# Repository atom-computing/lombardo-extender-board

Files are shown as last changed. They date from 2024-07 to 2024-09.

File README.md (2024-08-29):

# Lombardo Extender Board

Extender board for the front-panel connector on the [DAMC-FMC2ZUP
carrier](https://innovation.desy.de/technologies/microtca/boards/damc_fmc2zup/index_eng.html)
(commercially available at [CAEN
ELS](https://www.caenels.com/product/damc-fmc2zup/)).

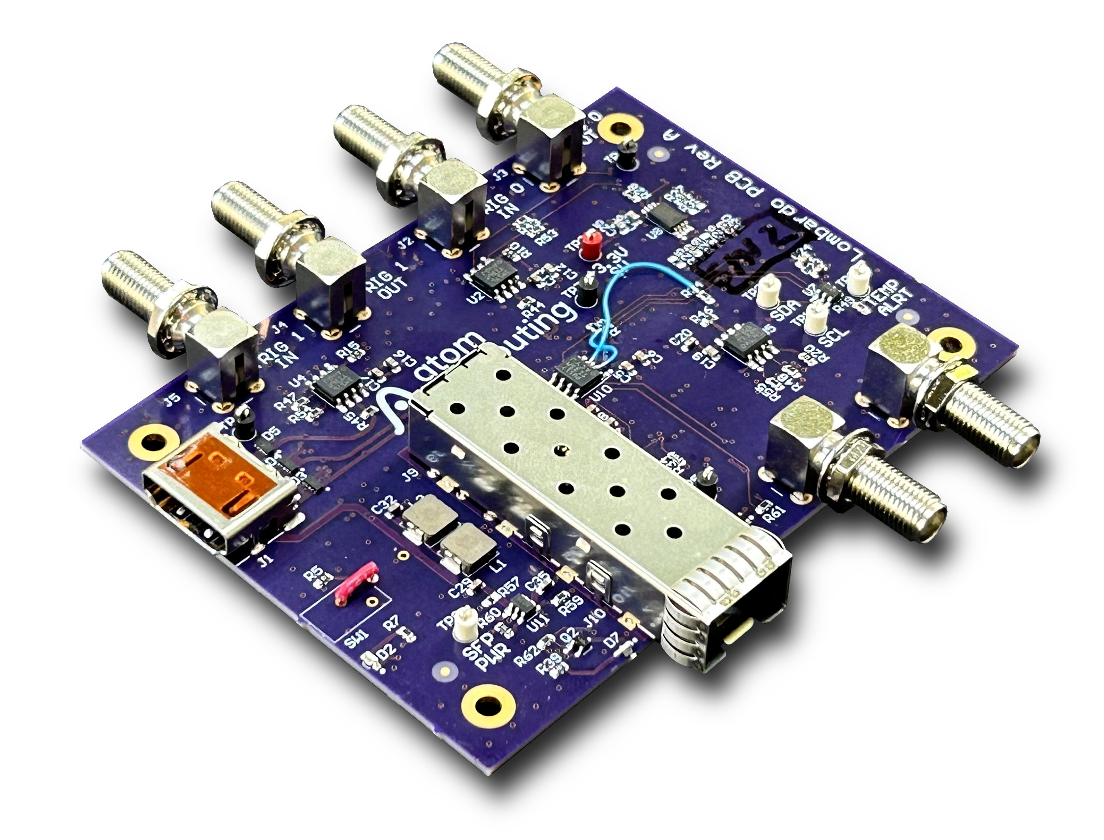
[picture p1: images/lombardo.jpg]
Lombardo Extender Board


## Features

* SFP+ cage, connected to the transceiver pins
* 2 trigger inputs and outputs (direction is SW configurable)
* clock input and output (direction is SW configurable)
* I2C EEPROM to store the identification information of the board
* I2C temperature sensor to monitor the board temperature

## License

Copyright (c) 2024, Atom Computing, Inc.

This project is licensed under CC BY-SA 4.0. See the [LICENSE.md](LICENSE.md)
file for details.

## Usage

### I2C communication, trigger and clock inputs/outputs

There are some I2C devices that need to be configured on this board at the
startup. The FPGA project on DAMC-FMC2ZUP should include an I2C controller
connected to the I2C bus that is connected to the front-panel connector. Please
refer to the [DAMC-FMC2ZUP - User's
Manual](https://www.caenels.com/product/damc-fmc2zup/) for information about the
pinout.

Similarly, all the differential pairs that are needed for triggers and clock
need to be instantiated.

### Connecting the board

Connect the board using to the front-panel connector of the DAMC-FMC2ZUP carrier
with a Micro HDMI to HDMI cable (see the list of tested cables
[below](#list-of-tested-hardware)) and turn on the switch. Please note that
some variants might not have a switch and the board turns on immediately when
connected to the carrier.

The LED D2 should turn on, indicating that the board is powered on.

### Initial check

Assuming you are running Linux on DAMC-FMC2ZUP, you can check whether the board
is operational by running `i2cdetect` command with the appropriate I2C bus
number (use `i2cdetect -l` to list all I2C buses).

```console
root@damc-fmc2zup:~# i2cdetect -l
i2c-3	i2c       	xiic-i2c [i2c_fplink]           	I2C adapter
i2c-1	i2c       	Cadence I2C at ff030000         	I2C adapter
i2c-4	i2c       	xiic-i2c [i2c_mmc]              	I2C adapter
i2c-2	i2c       	ZynqMP DP AUX                   	I2C adapter
i2c-0	i2c       	Cadence I2C at ff020000         	I2C adapter
i2c-5	i2c       	xiic-i2c [i2c_osc]              	I2C adapter
root@damc-fmc2zup:~# i2cdetect -r -y 3
     0  1  2  3  4  5  6  7  8  9  a  b  c  d  e  f
00:          -- -- -- -- -- -- -- -- -- -- -- -- --
10: -- -- -- -- -- -- -- -- -- -- -- -- -- -- -- --
20: -- -- -- -- -- -- -- -- -- -- -- -- -- -- -- --
30: -- -- -- -- -- -- -- -- -- 39 3a -- -- -- -- --
40: -- -- -- -- -- -- -- -- -- 49 -- -- -- -- -- --
50: -- -- -- -- 54 -- -- -- -- -- -- -- -- -- -- --
60: -- -- -- -- -- -- -- -- -- -- -- -- -- -- -- --
70: -- -- -- -- -- -- -- --
```

As shown in the example above, there should be 4 devices detected on the I2C
bus: 2 GPIO controllers at addresses 0x39 and 0x3a, an EEPROM at the address
0x54, and the temperature sensor at the address 0x49. When the SFP/SFP+ module
is enabled and inserted, there should be additional devices detected.

### Provided tools

#### Device tree overlay

The device tree overlay that describes this board is provided in the
`tools/device-tree-overlay` directory. To compile the overlay, run `make`, and
to load it run `make load`. This will load the drivers for the GPIO controllers,
the EEPROM, and the temperature sensor.

If you need to unload the overlay, run `make unload`.

#### Field Replaceable Unit (FRU)

The boards produced by Atom Computing have the EEPROM populated with the FRU
information, compliant with the IPMI FRU specification. To read the information,
dump the EEPROM to a file and run the `frugy` utility on it. Since the EEPROM
does not have a write-protect pin, please be careful when using it in order not
to overwrite the information.

```console
root@damc-fmc2zup:~# cat /sys/class/i2c-dev/i2c-3/device/3-0054/eeprom > fru.bin
root@damc-fmc2zup:~# frugy -d fru.bin

BoardInfo:
  mfg_date_time: 2024-07-08 17:25:00
  manufacturer: Atom Computing
  product_name: Lombardo
  serial_number: '1'
  part_number: '0000'
  fru_file_id: none

ProductInfo:
  manufacturer: Atom Computing
  product_name: Lombardo
  part_number: '0000'
  version: revA
  serial_number: '1'
  asset_tag: none
  fru_file_id: none
```

If you need to populate the EEPROM with the FRU information, there are a
template and instructions provided in the `tools/fru` directory.

#### SFP/SFP+ module

To enable the power to the SFP/SFP+ module and to enable the I2C communication
and enable the transmitter, run the following commands (after loading the device
tree overlay described in [Device tree overlay](#device-tree-overlay)):

```
root@damc-fmc2zup:~# gpioset $(gpiofind lombardo_sfp_power_en)=1
root@damc-fmc2zup:~# gpioset $(gpiofind lombardo_sfp_i2c_en)=1
root@damc-fmc2zup:~# gpioset $(gpiofind lombardo_sfp_tx_disable)=0
```

After that, you can use the SFP utility to read the information from the
SFP/SFP+ module. The SFP utility is provided in the `tools/sfp` directory. The
argument is the I2C bus number, the same as the one used to detect the devices
with the `i2cdetect` command.

```console
root@damc-fmc2zup:~/lombardo/tools/sfp-util# ./lombardo_sfp_info.py 3
  Info:
    Vendor name      : FS
    Vendor PN        : SFP-10GSR-85
    Vendor rev       : A
    Vendor SN        : F2310330129
    Vendor OUI       : 64:9d:99
    Date code        : 2023-09-22
    Wavelength       : 850 nm
    Length (OM2/50um): 300 m
    Length (OM4/50um): 0 m
    Encoding         : 0x06 (64B/66B)
    Baud rate        : 10300 Mbit/s
    Options:         : 0x001a
      Retimer/CDR      : 0
      Rate Select      : 0
      Tx Disable       : 1
      Tx Fault         : 1
      Loss of Signal   : 1
    Diagnostic       : 0x68
      Addr change      : 1
      External calib   : 0
      Internal calib   : 1
      DDM implemented  : 1
  Monitor:
    Temp     : 30.84 degC
    Vcc      : 3.121 V
    Tx Bias  : 6.05 mA
    Tx Power : 0.513 mW
    Rx Power : 0.497 mW
    Status/Control: 0x08
      Tx Disable: 0
      RS1 State : 0
      RS0 State : 0
      Tx Fault  : 0
      Rx LOS    : 0
```

## List of tested hardware

### Micro HDMI to HDMI cables

  * UGREEN 8K Micro HDMI to HDMI Cable 3.3FT, 2.1 Aluminum Shell Braided 48Gbps
    Ultra High Speed 8K@60Hz
    ([Amazon](https://www.amazon.com/UGREEN-Aluminum-Braided-Compatible-Raspberry/dp/B0BXGJGQMB))

### SFP+ modules

  * SFP-10GSR-85 ([fs.com](https://www.fs.com/products/11552.html)) 
    * note: this module does not have a built-in CDR and the signal integrity at 10 Gbps is marginal

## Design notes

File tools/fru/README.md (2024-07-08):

```
frugy -w -t -s BoardInfo.serial_number=1 -s ProductInfo.serial_number=1 ./lombardo_fru.yml
```

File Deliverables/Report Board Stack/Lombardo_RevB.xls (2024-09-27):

Board Stack Report
Stack Up |  | Layer Stack
Layer | Board Layer Stack | Name | Material | Thickness | Constant
1 |  | Top Overlay |  | 0mil
2 |  | Top Solder | Solder Resist | 1mil | 3.6
3 |  | Top |  | 1.701mil
4 |  | Prepreg 1 | FR408HR | 7.957mil | 3.61
5 |  | L2 |  | 0.689mil
6 |  | Core | FR408HR | 39mil | 3.61
7 |  | L3 |  | 0.689mil
8 |  | Prepreg 2 | FR408HR | 7.957mil | 3.61
9 |  | Bottom |  | 1.701mil
10 |  | Bottom Solder | Solder Resist | 1mil | 3.6
11 |  | Bottom Overlay |  | 0mil
 | Height : 61.694mil

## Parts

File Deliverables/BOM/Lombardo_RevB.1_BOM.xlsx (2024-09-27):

 |  |  |  |  |  |  | REVISIONS
 |  | BOM, | LOMBARDO |  |  |  | REV | DESCRIPTION |  | DATE | APPROVED
 |  |  |  |  |  |  | A | ENGINEERING RELEASE |  | 04/18/2024 | R. COXE
918 Parker St., Ste. A-13 |  | Rev |  | B.1 |  |  | B.1 | UPDATE R39 |  | 2024-08-28 | R. COXE
Berkeley, CA 94710
Quantity | Designator | Mfg PN |  | Case/Package | Value | Mfg |  |  | Description
13 | C1, C6, C7, C9, C12, C14, C16, C19, C21, C24, C26, C28, C35 | C0603C105K8PACTU |  | 603 | 1µF | Kemet |  |  | CAP CER 1uF 10V 10% 0603
18 | C2, C4, C5, C8, C10, C13, C15, C17, C18, C20, C22, C23, C27, C29, C31, C32, C34, C415 | C0603X104K3RACTU |  | 603 | 100nF | Kemet |  |  | CAP CER 0.1UF 25V X7R 0603
7 | C3, C36, C37, C38, C39, C40, C41 | CC0603JRNPO9BN102 |  | 603 | 1nF | Yageo |  |  | CAP CER 1000PF 50V C0G/NPO 0603
1 | C11 | DNP_CAP_0805 |  | 805 |  | DNP |  |  | DNP, CAP 0805
1 | C25 | C1608C0G1H103J080AA |  | 603 | 10nF | TDK Corporation |  |  | CAP CER 10000PF 50V C0G 0603
2 | C30, C33 | GRM31CR71A226KE15L |  | 1206 | 22µF | MURATA |  |  | CAP CER 22UF 10V X7R 1206
1 | C416 | C1608X7R1V105K080AE |  | 603 | 1µF | TDK Corporation |  |  | ±10% 35V Ceramic Capacitor X7R 0603 (1608 Metric)
1 | D1 | LTST-C193KRKT-2A |  | 603 | RED | Lite-On Inc. |  |  | LED RED CLEAR CHIP SMD 629nm, 1.9V, 0603
2 | D2, D6 | HSME-C120 |  | 2-SMD | GREEN | AVAGO TECHNOLOGIES |  |  | LED Green 1C 2A
3 | D3, D4, D5 | PUSB3AB4Z |  | 10-XFDFN |  | Nexperia USA Inc. |  |  | TVS DIODE BIDIRECTIONAL 3.3VWM 5VC DFN2510A-10
1 | D7 | HSMA-C120 |  | 603 | AMBER | Broadcom Limited |  |  | LED AMBER CLEAR CHIP SMD R/A 0603
6 | D8, D9, D10, D11, D12, D13 | PESD3V3Z1BCSFYL |  | 201 |  | Nexperia USA Inc. |  |  | TVS DIODE 3.3VWM 4.8VC DSN0603-2
1 | D14 | DT1240A-08LP3810-7 |  | 9-UDFN |  | Diodes Incorporated |  |  | TVS DIODE 3.3VWM 10V U-DFN3810-9
1 | J1 | 2086581061 |  | SMD-RA |  | Molex |  |  | HDMI 2.1 Receptacle Connector 19 Position Surface Mount, Right Angle; Through Hole
6 | J2, J3, J4, J5, J6, J7 | 0732512410 |  | SMA RA |  | Molex |  |  | Conn; RF; SMA Rt Angle PCB Jack Thru Hole 50 Ohm Bulkhead
1 | J9 | UE76-A20-2000T |  | 0.8mm |  | Amphenol ICC (Commercial Products) |  |  | 20 Position SFP+ Receptacle Connector Solder Surface Mount, Right Angle
1 | J10 | 2110304-1 |  | None |  | TE Connectivity AMP Connectors |  |  | Position SFP+ Cage Connector Solder Through Hole, Right Angle
2 | L1, L2 | IHLP2020BZER4R7M11 |  | SMD | 4.7µH | Vishay Dale |  |  | FIXED IND 4.7UH 3.2A 81.3 MOHM
2 | Q1, Q2 | BSS138W |  |  |  | ON SEMICONDUCTOR |  |  | MOSFET N-CH 50V 210MA SC70
2 | R1, R3 | RC0603FR-07100KL |  | 603 | 100k | Yageo |  |  | RES SMD 100K OHM 1% 1/10W 0603
5 | R2, R7, R44, R45, R46 | ERJ-3EKF1000V |  | 603 | 100 | Panasonic Electronic Components |  |  | RES SMD 100 OHM 1% 1/10W 0603
1 | R4 | RCV12061M00FKEA |  | 1206 | 1M | Vishay Dale |  |  | 1 ±1% 0.25W, 1/4W Chip Resistor 1206 (3216 Metric) High Voltage Thick Film
14 | R5, R9, R10, R12, R13, R14, R15, R20, R21, R22, R27, R29, R30, R63 | RC0603FR-070RL |  | 603 | 0 | Yageo |  |  | RES 0 OHM JUMPER 1/10W 0603
1 | R6 | ERJ-3EKF2322V |  | 603 | 23.2k | Panasonic Electronic Components |  |  | RES SMD 23.2K OHM 1% 1/10W 0603
25 | R8, R11, R16, R19, R23, R24, R28, R43, R47, R48, R49, R50, R51, R52, R53, R54, R55, R56, R58, R59, R61, R62, R64, R65, R539 | ERJ-3EKF1002V |  | 603 | 10k | Panasonic Electronic Components |  |  | RES SMD 10K OHM 1% 1/10W 0603
2 | R17, R18 | RC0603FR-071KL |  | 603 | 1k | Yageo |  |  | RES SMD 1K OHM 1% 1/10W 0603
7 | R25, R26, R31, R40, R41, R42, R57 | DNP_RES_0603 |  | 603 |  | DNP |  |  | DNP, RES 0603
6 | R32, R33, R34, R35, R36, R37 | RC0603FR-074K7L |  | 603 | 4.7k | Yageo |  |  | RES SMD 4.7K OHM 1% 1/10W 0603
1 | R38 | RC0603FR-07220RL |  | 603 | 220 | Yageo |  |  | RES SMD 220 OHM 1% 1/10W 0603
1 | R39 | ERJ-3EKF2800V |  | 603 | 280 | Panasonic Electronic Components |  |  | RES SMD 280 OHM 1% 1/10W 0603
1 | R60 | RT0603BRD0752K3L |  | 603 | 52.3k | Yageo |  |  | RES SMD 52.3K 0.1% 1/10W 0603
1 | SW1 | AS11AV |  | .100" TH-RA |  | NKK Switches |  |  | SWITCH SLIDE SPST 0.4VA 28V Through Hole, Right Angle, Vertical
4 | TP1, TP2, TP8, TP9 | 5002 |  |  | White | Keystone |  |  | Test Point, White, 1-Pin THD, RoHS, Bulk
1 | TP3 | 5000 |  |  | Red | Keystone |  |  | Test Point, Red, 1-Pin THD, RoHS, Bulk
4 | TP4, TP5, TP6, TP7 | 5001 |  |  | Black | Keystone |  |  | Test Point, Black, 1-Pin THD, RoHS, Bulk
1 | U1 | TPS2553DBVR |  | SOT-23-6 |  | Texas Instruments |  |  | Power Switch/Driver 1:1 N-Channel 1.5A SOT-23-6
2 | U2, U4 | SN65LVDM176DR |  | SOP |  | Texas Instruments |  |  | 1/1 Transceiver Half LVDS 8-SOIC
1 | U3 | SN74LVC2G34DCKR |  | SC-70-6 |  | Texas Instruments |  |  | Buffer, Non-Inverting 2 Element 1 Bit per Element Push-Pull Output SC-70-6
1 | U5 | SN65MLVD201DR |  | SOP |  | Texas Instruments |  |  | 1/1 Transceiver Half LVDS, Multipoint 8-SOIC
1 | U6 | SN74LVC1G34DBVR |  | LSSOP |  | Texas Instruments |  |  | Buffer, Non-Inverting 1 Element 1 Bit per Element Push-Pull Output SOT-23-5
1 | U7 | MAX6626PMUT+T |  | SOT-23-6 |  | Maxim |  |  | Temperature Sensor Digital, Local -55°C ~ 125°C 12 b SOT-6
1 | U8 | AT24HC02C-XHM-B |  | 8-TSSOP |  | Microchip Technology |  |  | IC EEPROM 2KBIT I2C 1MHZ 8TSSOP
2 | U9, U46 | PCA9554AD,118 |  | 16-SOIC |  | NXP USA Inc. |  |  | I/O GPIO Expander 8 I2C, SMBus 400 kHz 16-SO
1 | U10 | TCA9517DR |  | 8-SOIC |  | Texas Instruments |  |  | Voltage Level Translator Bidirectional 1 Circuit 2 Channel 8-SOIC
1 | U11 | MAX4995BAUT+T |  | SOT-23-6 |  | Analog Devices Inc./Maxim Integrated |  |  | IC CURRENT SWITCH ADJ 10% SOT-23-6

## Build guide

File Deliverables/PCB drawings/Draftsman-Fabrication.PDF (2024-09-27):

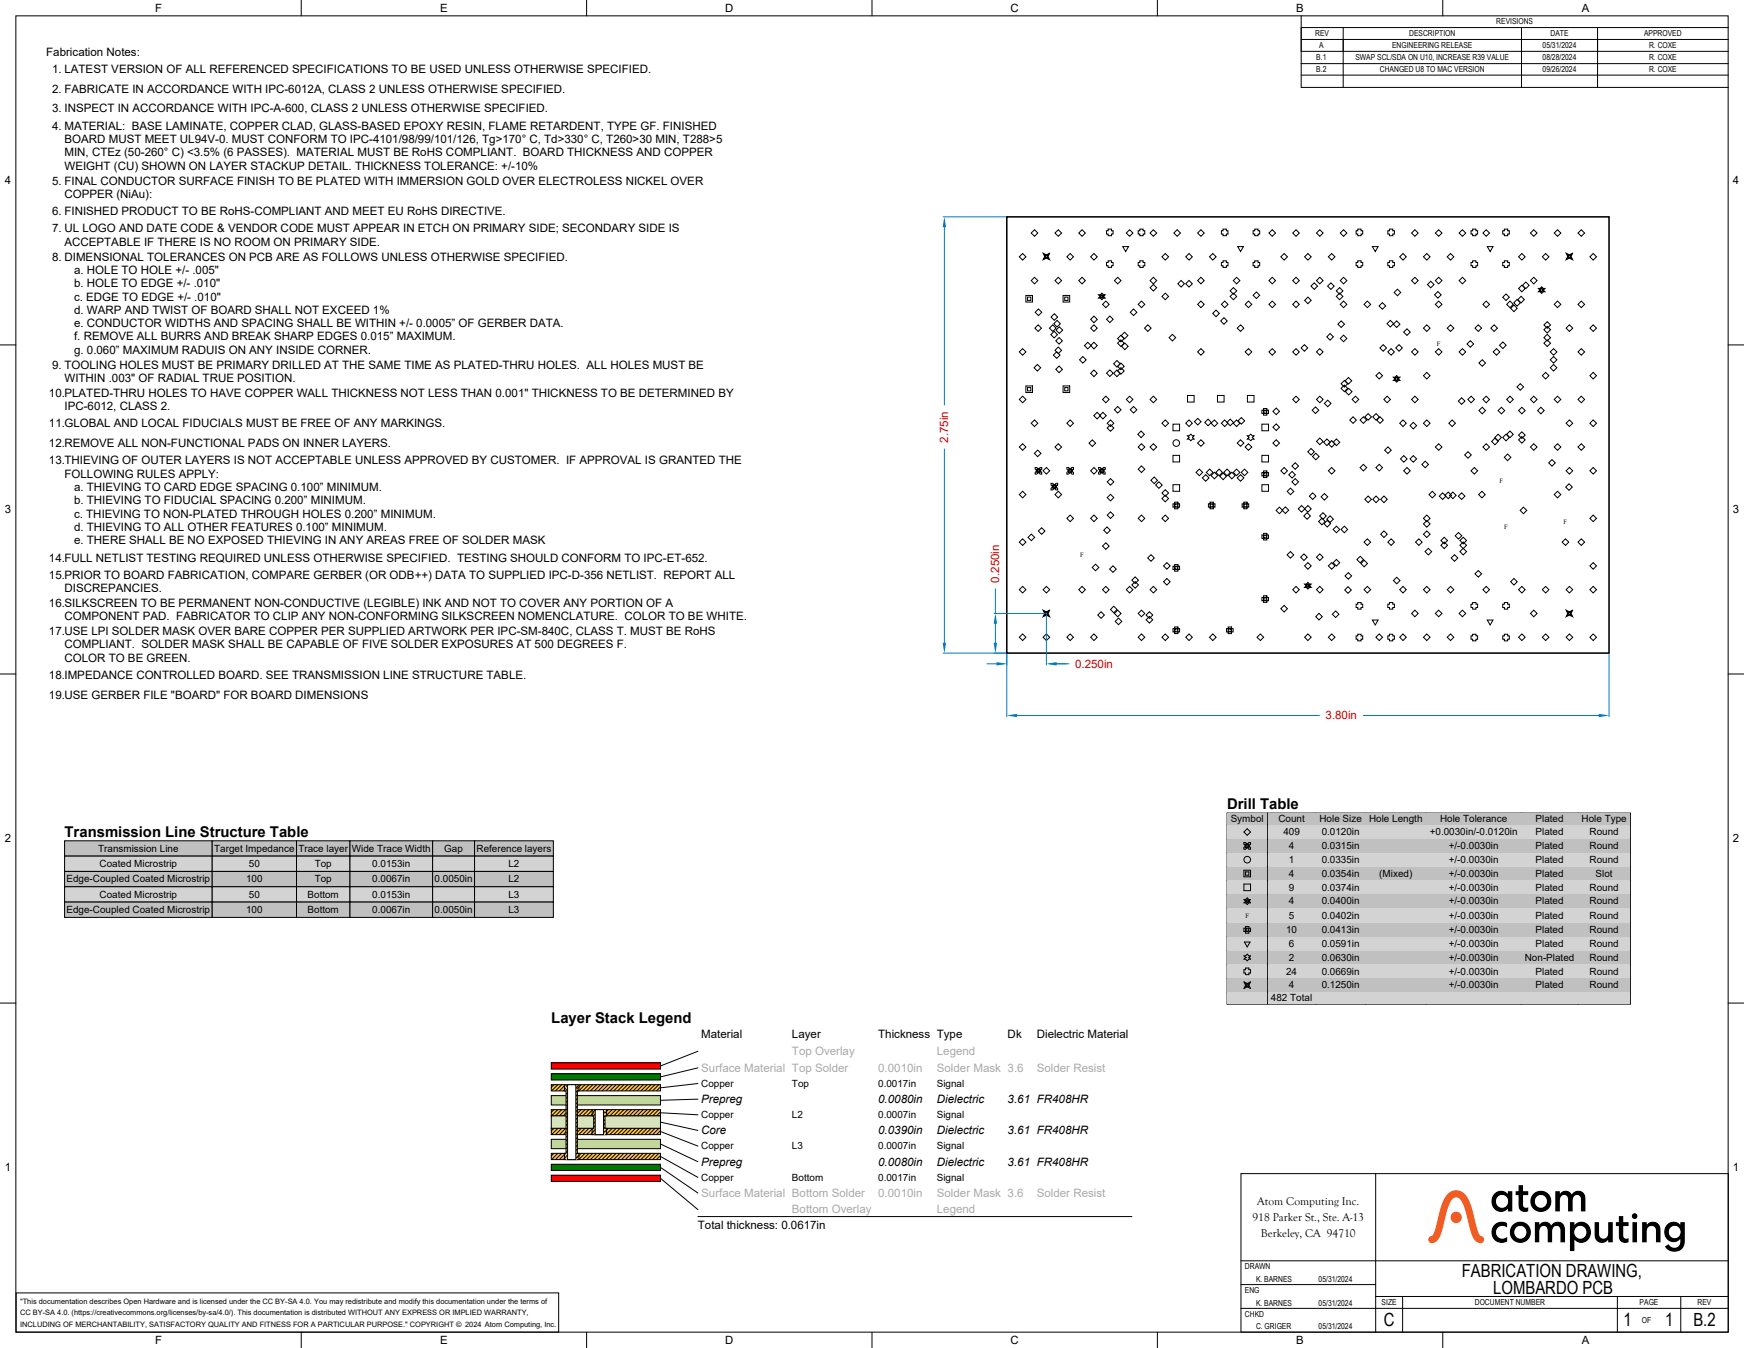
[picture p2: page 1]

Fabrication Notes:
1. LATEST VERSION OF ALL REFERENCED SPECIFICATIONS TO BE USED UNLESS OTHERWISE SPECIFIED.
2. FABRICATE IN ACCORDANCE WITH IPC-6012A, CLASS 2 UNLESS OTHERWISE SPECIFIED.
3. INSPECT IN ACCORDANCE WITH IPC-A-600, CLASS 2 UNLESS OTHERWISE SPECIFIED.
MATERIAL: BASE LAMINATE, COPPER CLAD, GLASS-BASED EPOXY RESIN, FLAME RETARDENT, TYPE GF. FINISHED
BOARD MUST MEET UL94V-0. MUST CONFORM TO IPC-4101/98/99/101/126, Tg>170° C, Td>330° C, T260>30 MIN, T288>5
MIN, CTEz (50-260° C) <3.5% (6 PASSES). MATERIAL MUST BE RoHS COMPLIANT. BOARD THICKNESS AND COPPER
WEIGHT (CU) SHOWN ON LAYER STACKUP DETAIL. THICKNESS TOLERANCE: +/-10%
FINAL CONDUCTOR SURFACE FINISH TO BE PLATED WITH IMMERSION GOLD OVER ELECTROLESS NICKEL OVER
COPPER (NiAu):
6. FINISHED PRODUCT TO BE RoHS-COMPLIANT AND MEET EU RoHS DIRECTIVE.
UL LOGO AND DATE CODE & VENDOR CODE MUST APPEAR IN ETCH ON PRIMARY SIDE; SECONDARY SIDE IS
ACCEPTABLE IF THERE IS NO ROOM ON PRIMARY SIDE.
DIMENSIONAL TOLERANCES ON PCB ARE AS FOLLOWS UNLESS OTHERWISE SPECIFIED.
a. HOLE TO HOLE +/- .005"
b. HOLE TO EDGE +/- .010"
c. EDGE TO EDGE +/- .010"
d. WARP AND TWIST OF BOARD SHALL NOT EXCEED 1%
e. CONDUCTOR WIDTHS AND SPACING SHALL BE WITHIN +/- 0.0005” OF GERBER DATA.
f. REMOVE ALL BURRS AND BREAK SHARP EDGES 0.015” MAXIMUM.
g. 0.060” MAXIMUM RADUIS ON ANY INSIDE CORNER.
TOOLING HOLES MUST BE PRIMARY DRILLED AT THE SAME TIME AS PLATED-THRU HOLES. ALL HOLES MUST BE
WITHIN .003" OF RADIAL TRUE POSITION.
PLATED-THRU HOLES TO HAVE COPPER WALL THICKNESS NOT LESS THAN 0.001" THICKNESS TO BE DETERMINED BY
IPC-6012, CLASS 2.
11.GLOBAL AND LOCAL FIDUCIALS MUST BE FREE OF ANY MARKINGS.
12.REMOVE ALL NON-FUNCTIONAL PADS ON INNER LAYERS.
THIEVING OF OUTER LAYERS IS NOT ACCEPTABLE UNLESS APPROVED BY CUSTOMER. IF APPROVAL IS GRANTED THE
FOLLOWING RULES APPLY:
a. THIEVING TO CARD EDGE SPACING 0.100” MINIMUM.
b. THIEVING TO FIDUCIAL SPACING 0.200” MINIMUM.
c. THIEVING TO NON-PLATED THROUGH HOLES 0.200” MINIMUM.
d. THIEVING TO ALL OTHER FEATURES 0.100” MINIMUM.
e. THERE SHALL BE NO EXPOSED THIEVING IN ANY AREAS FREE OF SOLDER MASK
14.FULL NETLIST TESTING REQUIRED UNLESS OTHERWISE SPECIFIED. TESTING SHOULD CONFORM TO IPC-ET-652.
PRIOR TO BOARD FABRICATION, COMPARE GERBER (OR ODB++) DATA TO SUPPLIED IPC-D-356 NETLIST. REPORT ALL
DISCREPANCIES.
SILKSCREEN TO BE PERMANENT NON-CONDUCTIVE (LEGIBLE) INK AND NOT TO COVER ANY PORTION OF A
COMPONENT PAD. FABRICATOR TO CLIP ANY NON-CONFORMING SILKSCREEN NOMENCLATURE. COLOR TO BE WHITE.
USE LPI SOLDER MASK OVER BARE COPPER PER SUPPLIED ARTWORK PER IPC-SM-840C, CLASS T. MUST BE RoHS
COMPLIANT. SOLDER MASK SHALL BE CAPABLE OF FIVE SOLDER EXPOSURES AT 500 DEGREES F.
COLOR TO BE GREEN.
18.IMPEDANCE CONTROLLED BOARD. SEE TRANSMISSION LINE STRUCTURE TABLE.
19.USE GERBER FILE "BOARD" FOR BOARD DIMENSIONS

Symbol | Count | Hole Size | Hole Length | Hole Tolerance | Plated | Hole Type

Transmission Line Structure Table

409 | 0.0120in | | +0.0030in/-0.0120in | Plated | Round

Coated Microstrip | 50 | Top | 0.0153in | | L2

1 | 0.0335in | | +/-0.0030in | Plated | Round
4 | 0.0354in | (Mixed) | +/-0.0030in | Plated | Slot
9 | 0.0374in | | +/-0.0030in | Plated | Round
4 | 0.0400in | | +/-0.0030in | Plated | Round

Edge-Coupled Coated Microstrip | 100 | Top | 0.0067in | 0.0050in | L2

Coated Microstrip | 50 | Bottom | 0.0153in | | L3

Edge-Coupled Coated Microstrip | 100 | Bottom | 0.0067in | 0.0050in | L3

F | | | 5 | 0.0402in | | +/-0.0030in | Plated | Round

10 | 0.0413in | | +/-0.0030in | Plated | Round
6 | 0.0591in | | +/-0.0030in | Plated | Round
2 | 0.0630in | | +/-0.0030in | Non-Plated | Round
24 | 0.0669in | | +/-0.0030in | Plated | Round
4 | 0.1250in | | +/-0.0030in | Plated | Round
482 Total

Surface Material Bottom Solder 0.0010in Solder Mask 3.6 Solder Resist

Atom Computing Inc. 918 Parker St., Ste. A-13 Berkeley, CA 94710

DRAWN K. BARNES 05/31/2024 | FABRICATION DRAWING, LOMBARDO PCB

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

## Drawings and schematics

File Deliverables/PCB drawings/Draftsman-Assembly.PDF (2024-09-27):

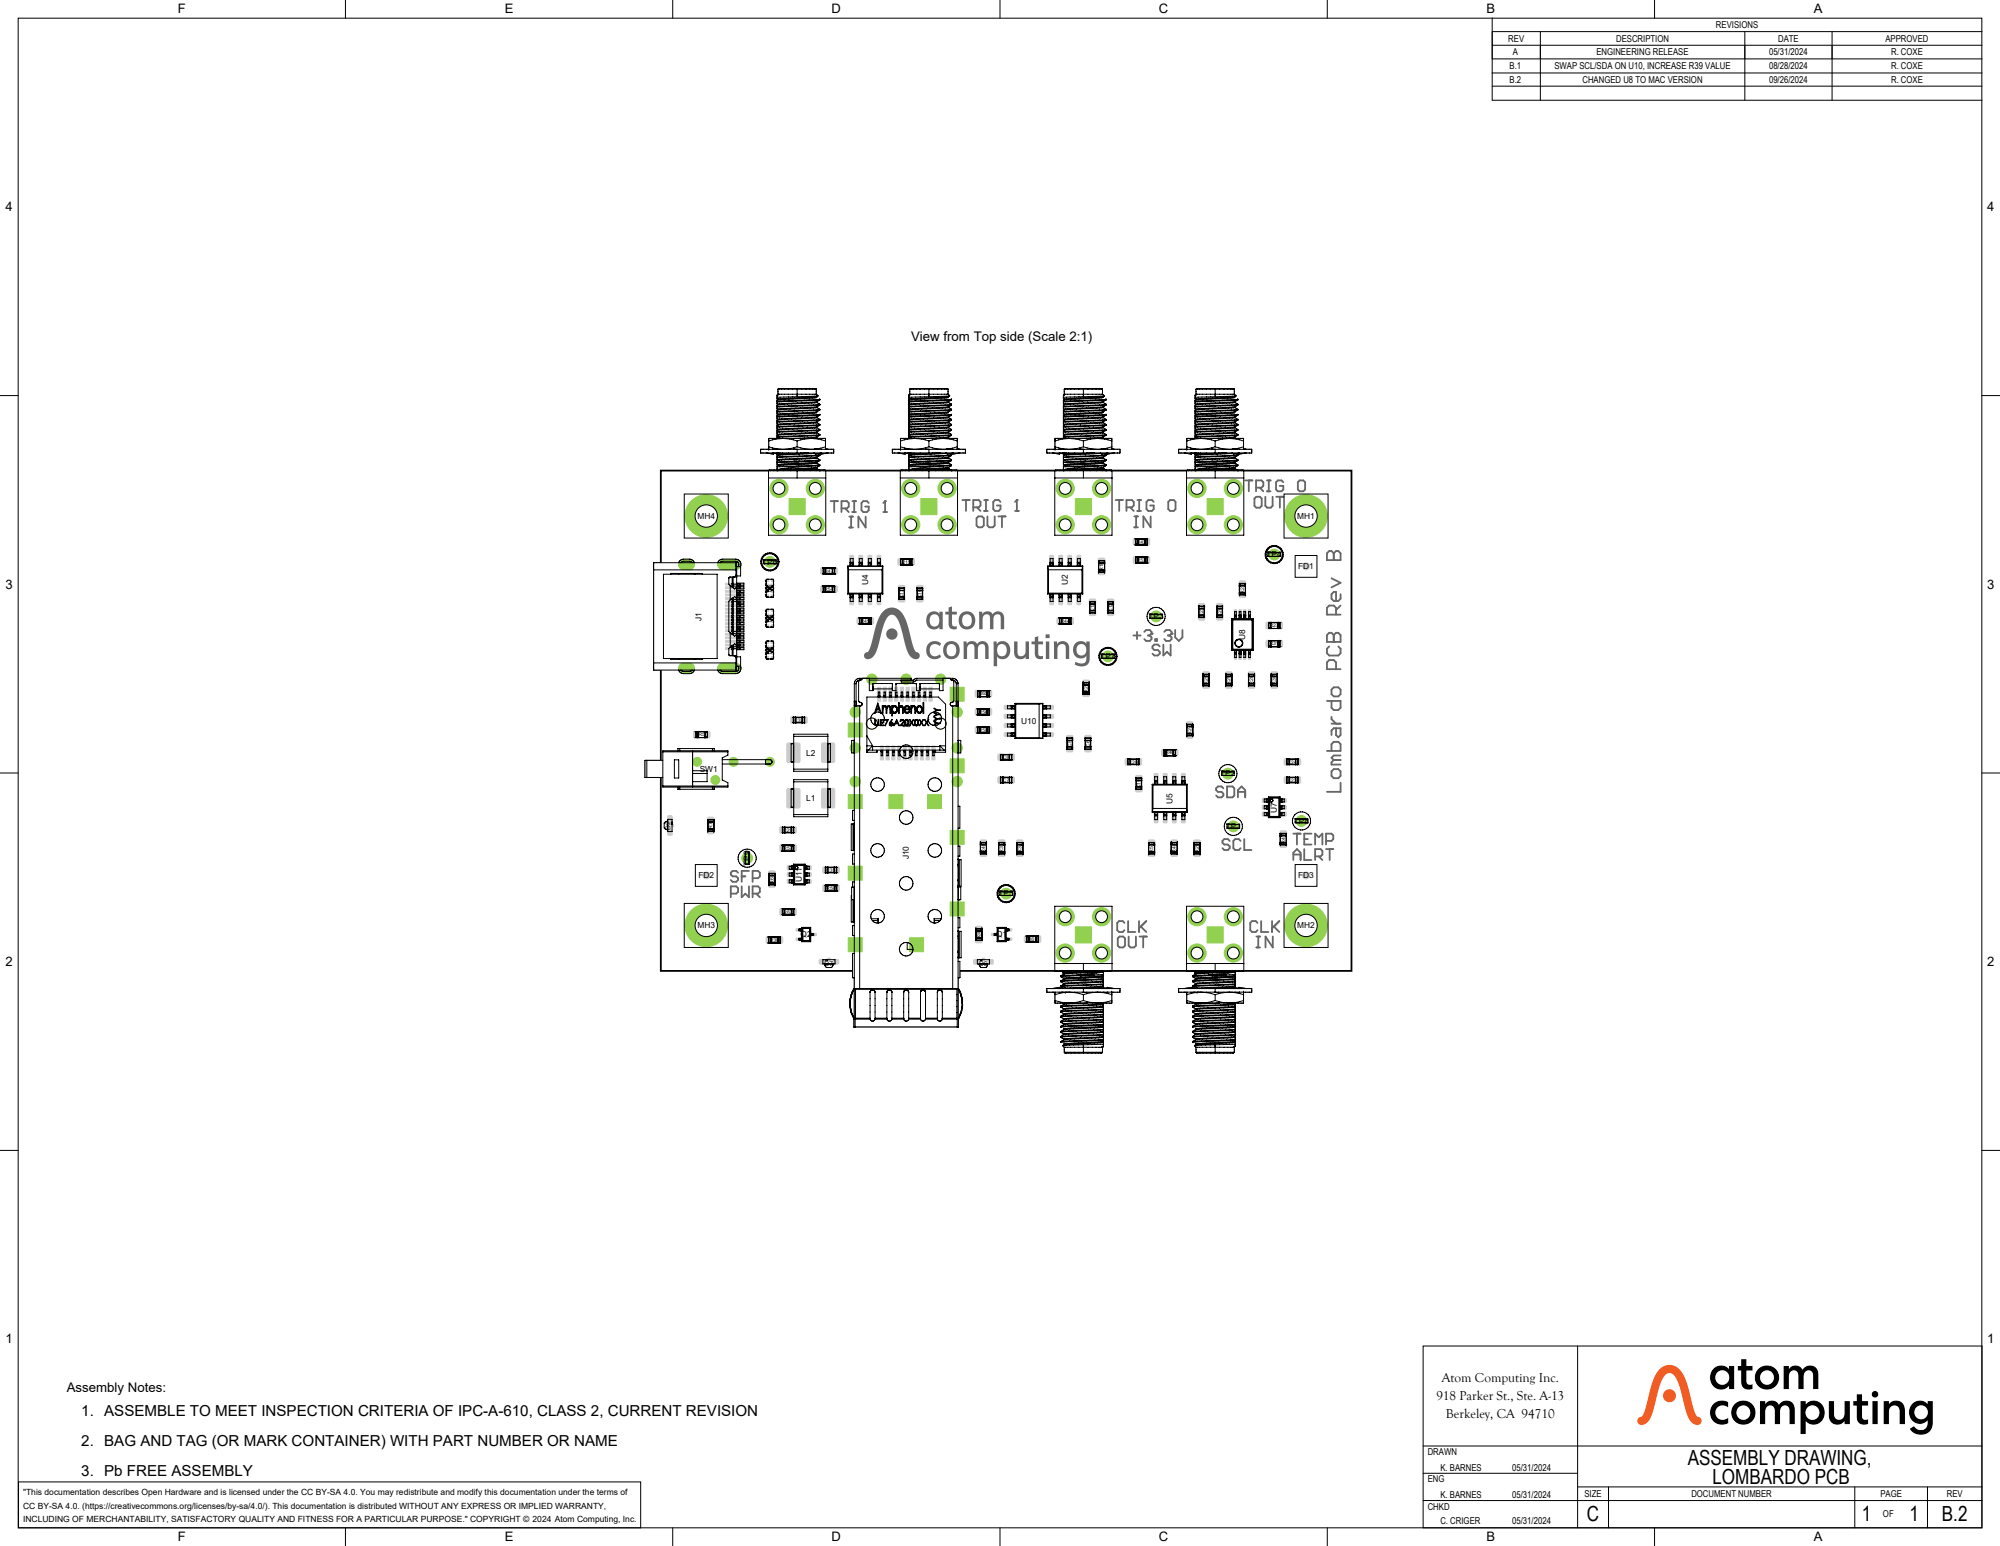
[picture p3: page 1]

View from Top side (Scale 2:1)

Atom Computing Inc. 918 Parker St., Ste. A-13 Berkeley, CA 94710

Assembly Notes:
1. ASSEMBLE TO MEET INSPECTION CRITERIA OF IPC-A-610, CLASS 2, CURRENT REVISION
2. BAG AND TAG (OR MARK CONTAINER) WITH PART NUMBER OR NAME
3. Pb FREE ASSEMBLY

DRAWN K. BARNES 05/31/2024 | ASSEMBLY DRAWING, LOMBARDO PCB

"This documentation describes Open Hardware and is licensed under the CC BY-SA 4.0. You may redistribute and modify this documentation under the terms of
CC BY-SA 4.0. (https://creativecommons.org/licenses/by-sa/4.0/). This documentation is distributed WITHOUT ANY EXPRESS OR IMPLIED WARRANTY,
INCLUDING OF MERCHANTABILITY, SATISFACTORY QUALITY AND FITNESS FOR A PARTICULAR PURPOSE." COPYRIGHT © 2024

SIZE | DOCUMENT NUMBER | PAGE | REV

CHKD C. CRIGER 05/31/2024 | C | | 1 OF 1 | B.2

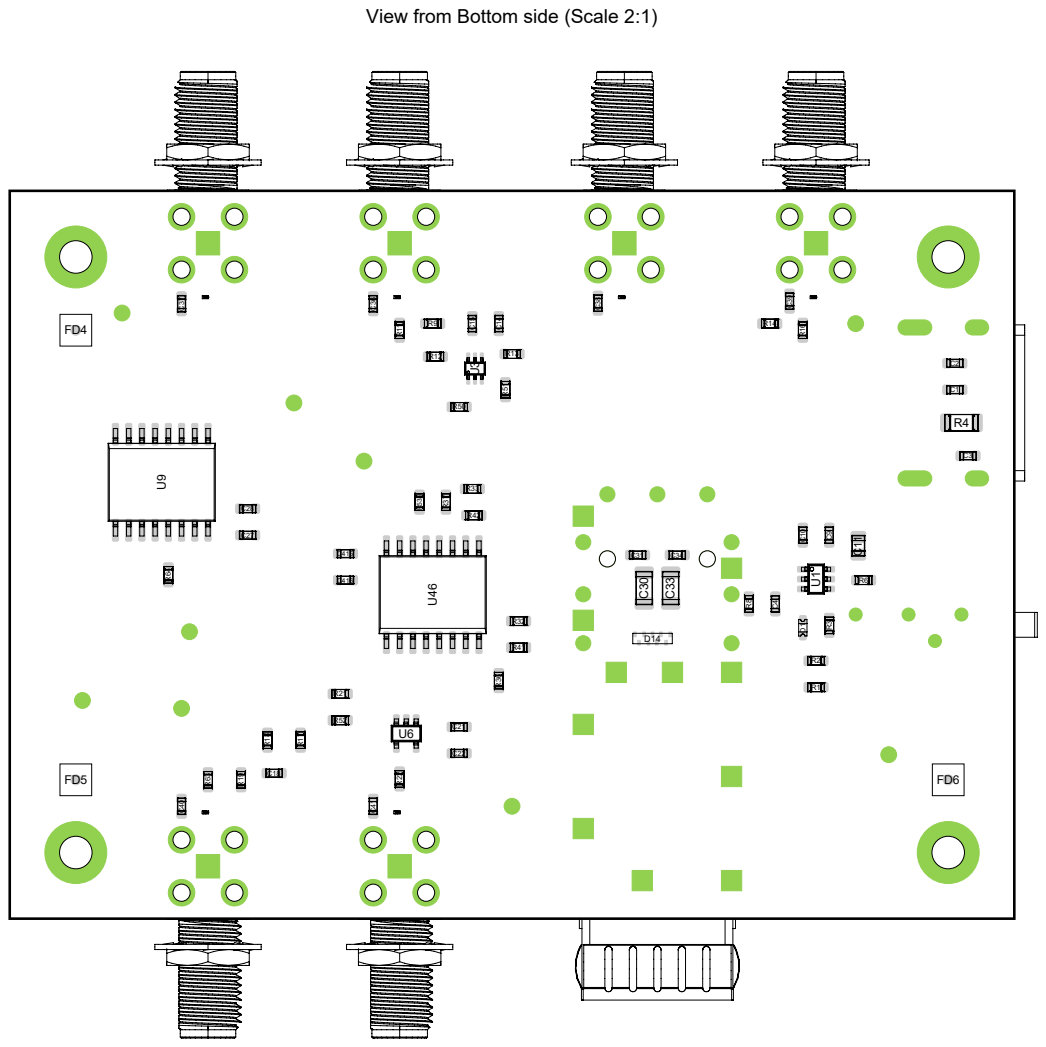
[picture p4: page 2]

View from Bottom side (Scale 2:1)

Atom Computing Inc. 918 Parker St., Ste. A-13 Berkeley, CA 94710

DRAWN K. BARNES 05/31/2024 | ASSEMBLY DRAWING, LOMBARDO PCB

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

SIZE | DOCUMENT NUMBER | PAGE | REV

CHKD C. CRIGER 05/31/2024 | C | | 1 OF 1 | B.2

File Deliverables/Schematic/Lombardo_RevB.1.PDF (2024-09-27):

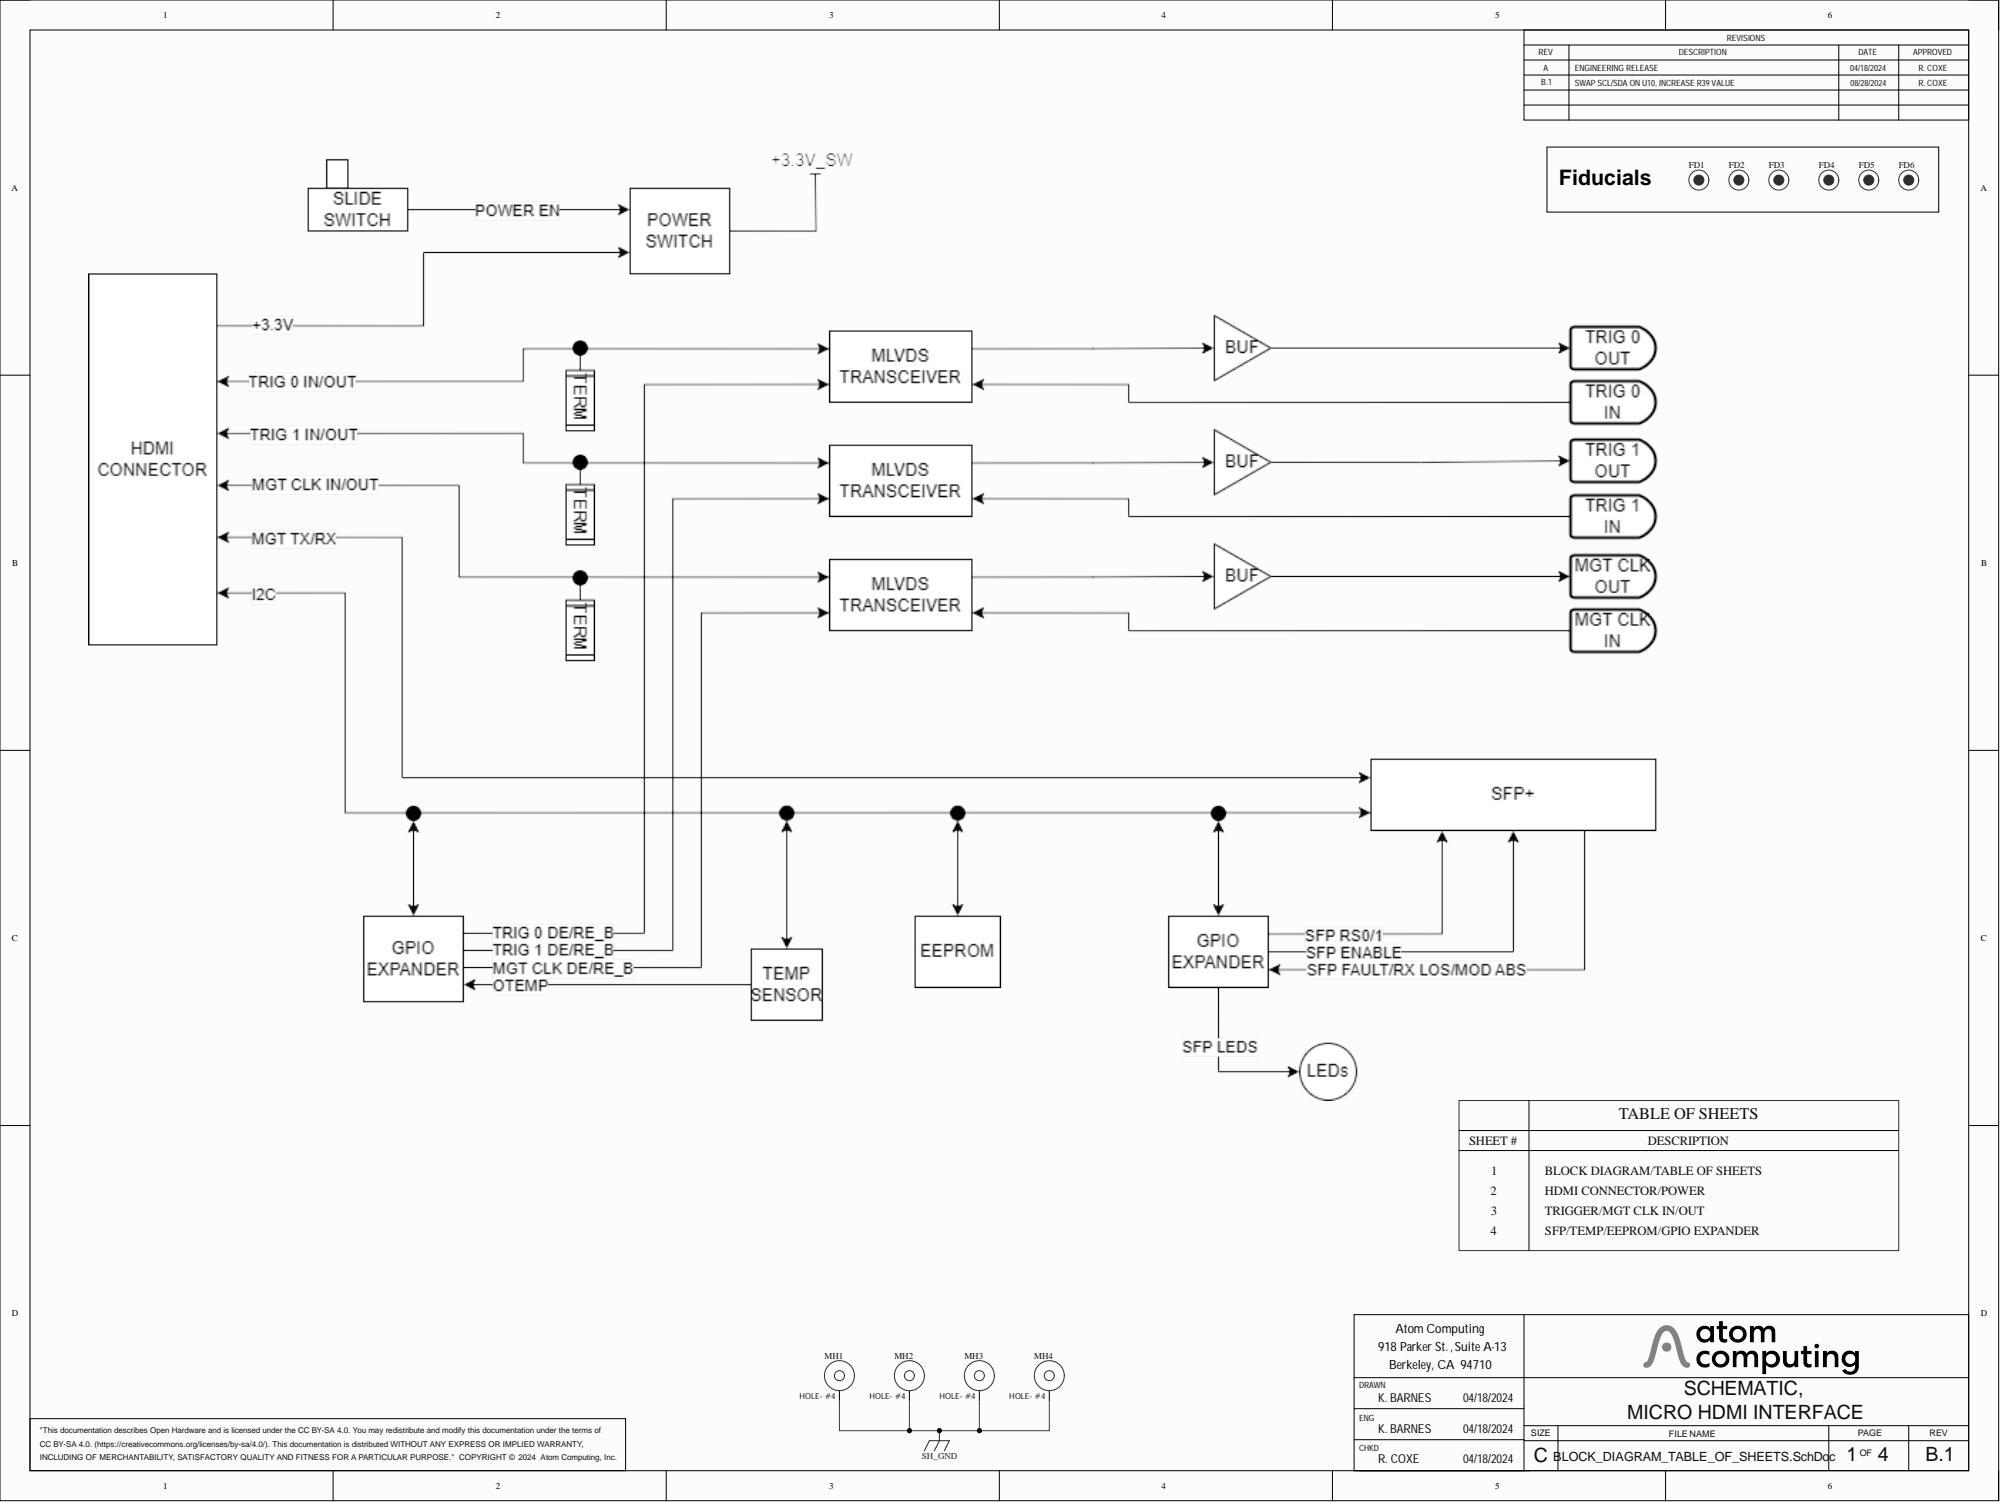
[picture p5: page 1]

REV | DESCRIPTION | DATE | APPROVED

A | ENGINEERING RELEASE | 04/18/2024 | R. COXE
B.1 | SWAP SCL/SDA ON U10, INCREASE R39 VALUE | 08/28/2024 | R. COXE

TABLE OF SHEETS

SHEET # | DESCRIPTION

1 2 3 4 | BLOCK DIAGRAM/TABLE OF SHEETS HDMI CONNECTOR/POWER TRIGGER/MGT CLK IN/OUT SFP/TEMP/EEPROM/GPIO EXPANDER

Atom Computing 918 Parker St. , Suite A-13 Berkeley, CA 94710

DRAWN K. BARNES 04/18/2024 | SCHEMATIC, MICRO HDMI INTERFACE

"This documentation describes Open Hardware and is licensed under the CC BY-SA 4.0. You may redistribute and modify this documentation under the terms of
CC BY-SA 4.0. (https://creativecommons.org/licenses/by-sa/4.0/). This documentation is distributed WITHOUT ANY EXPRESS OR IMPLIED WARRANTY,

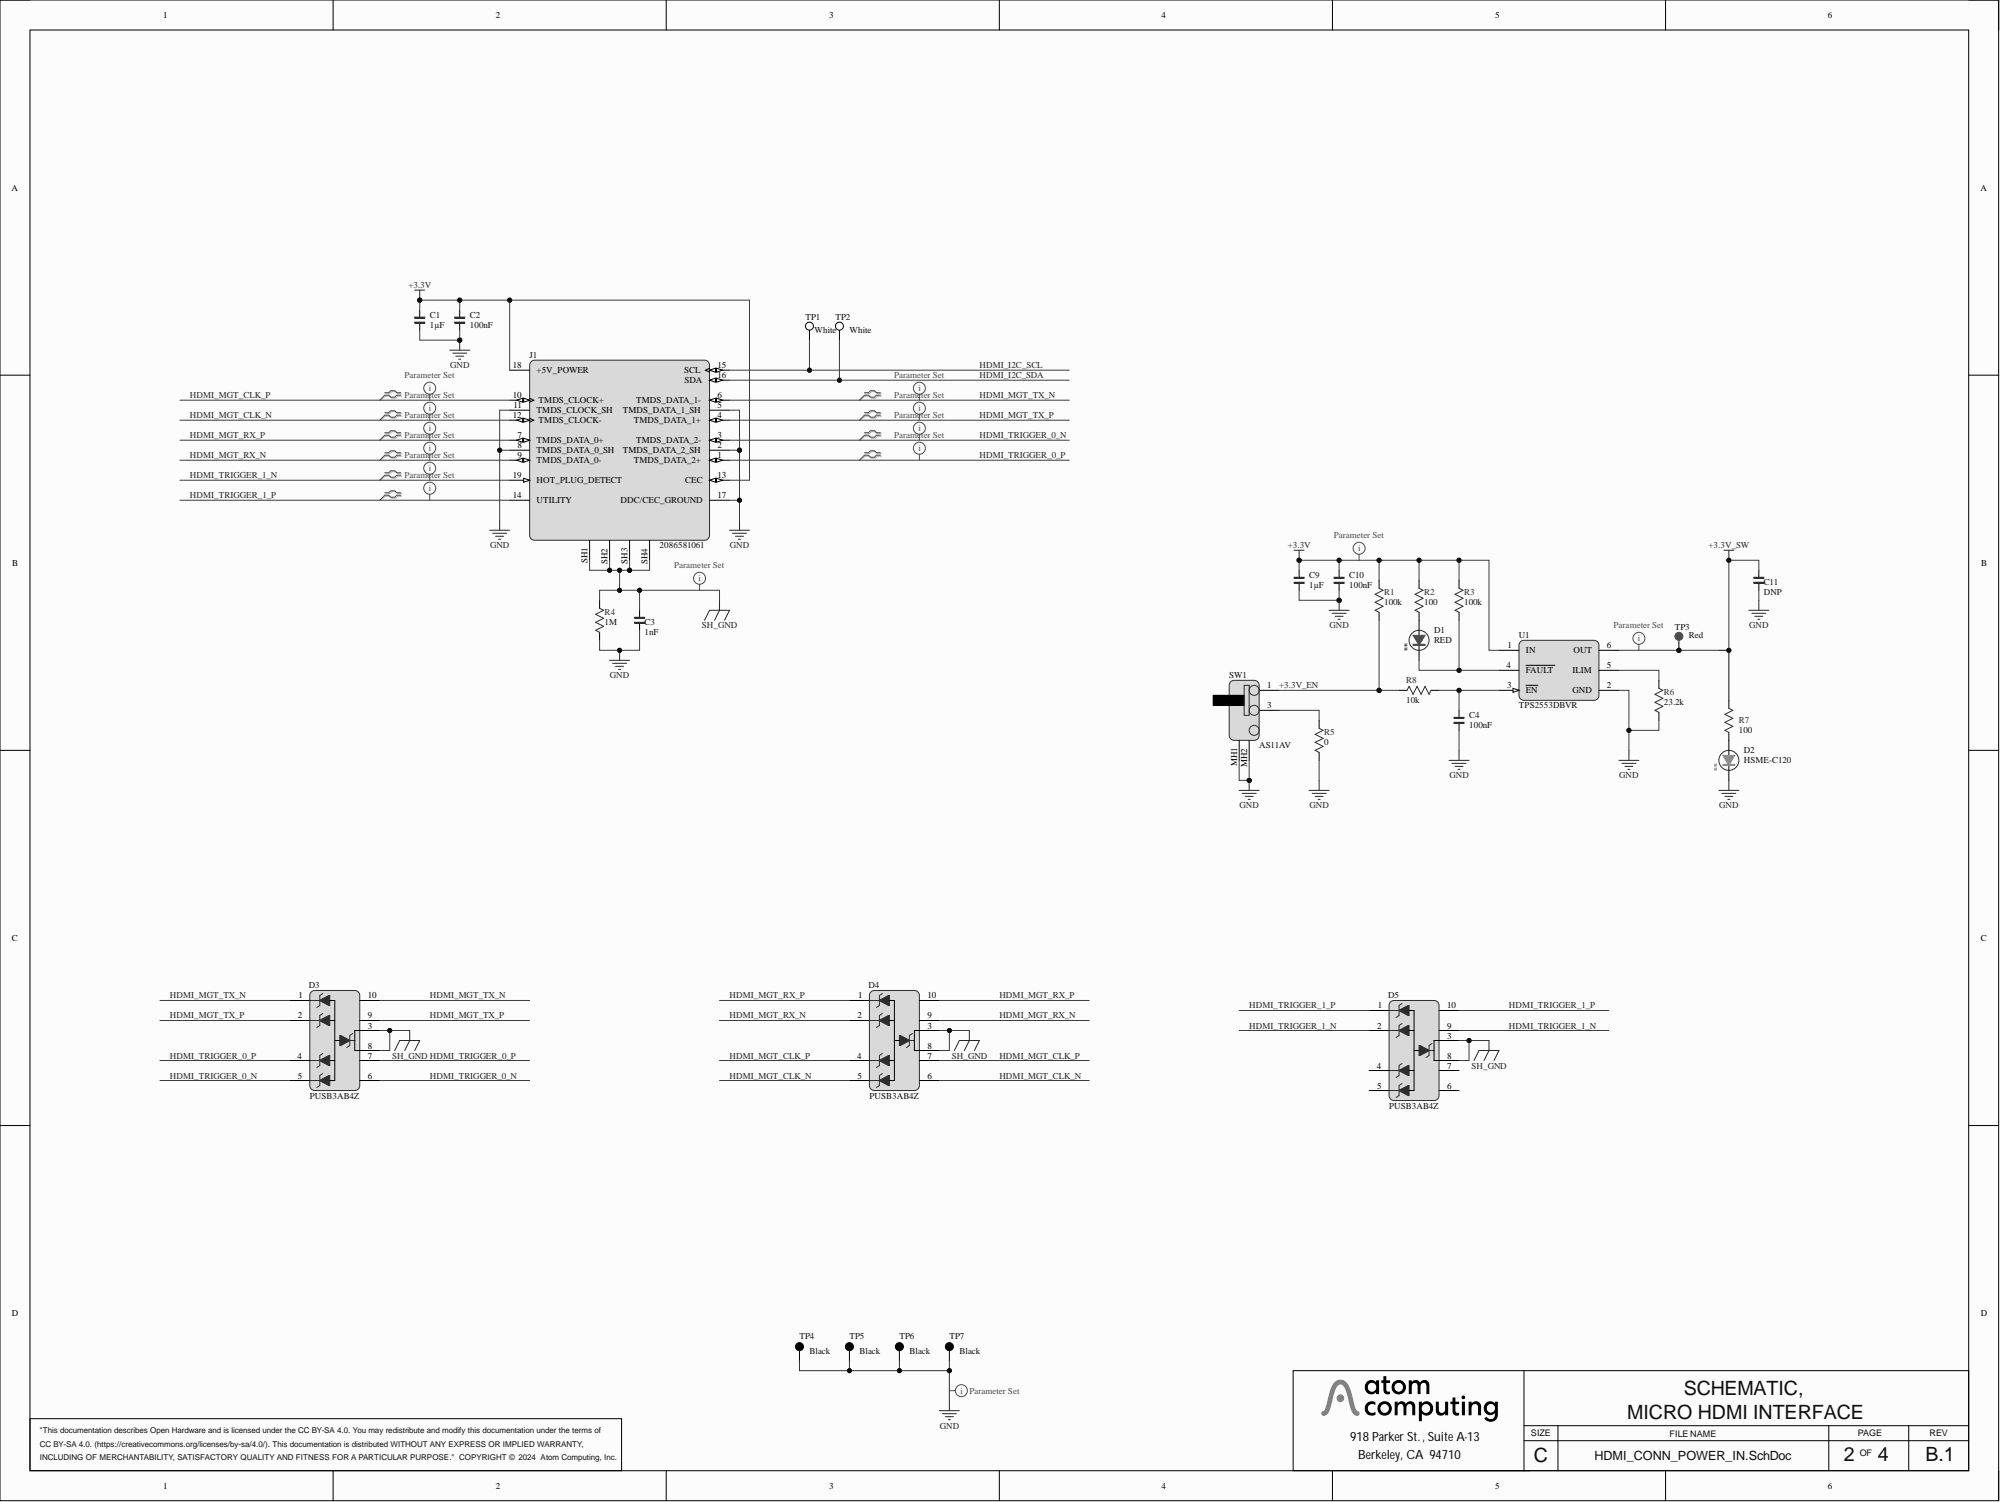
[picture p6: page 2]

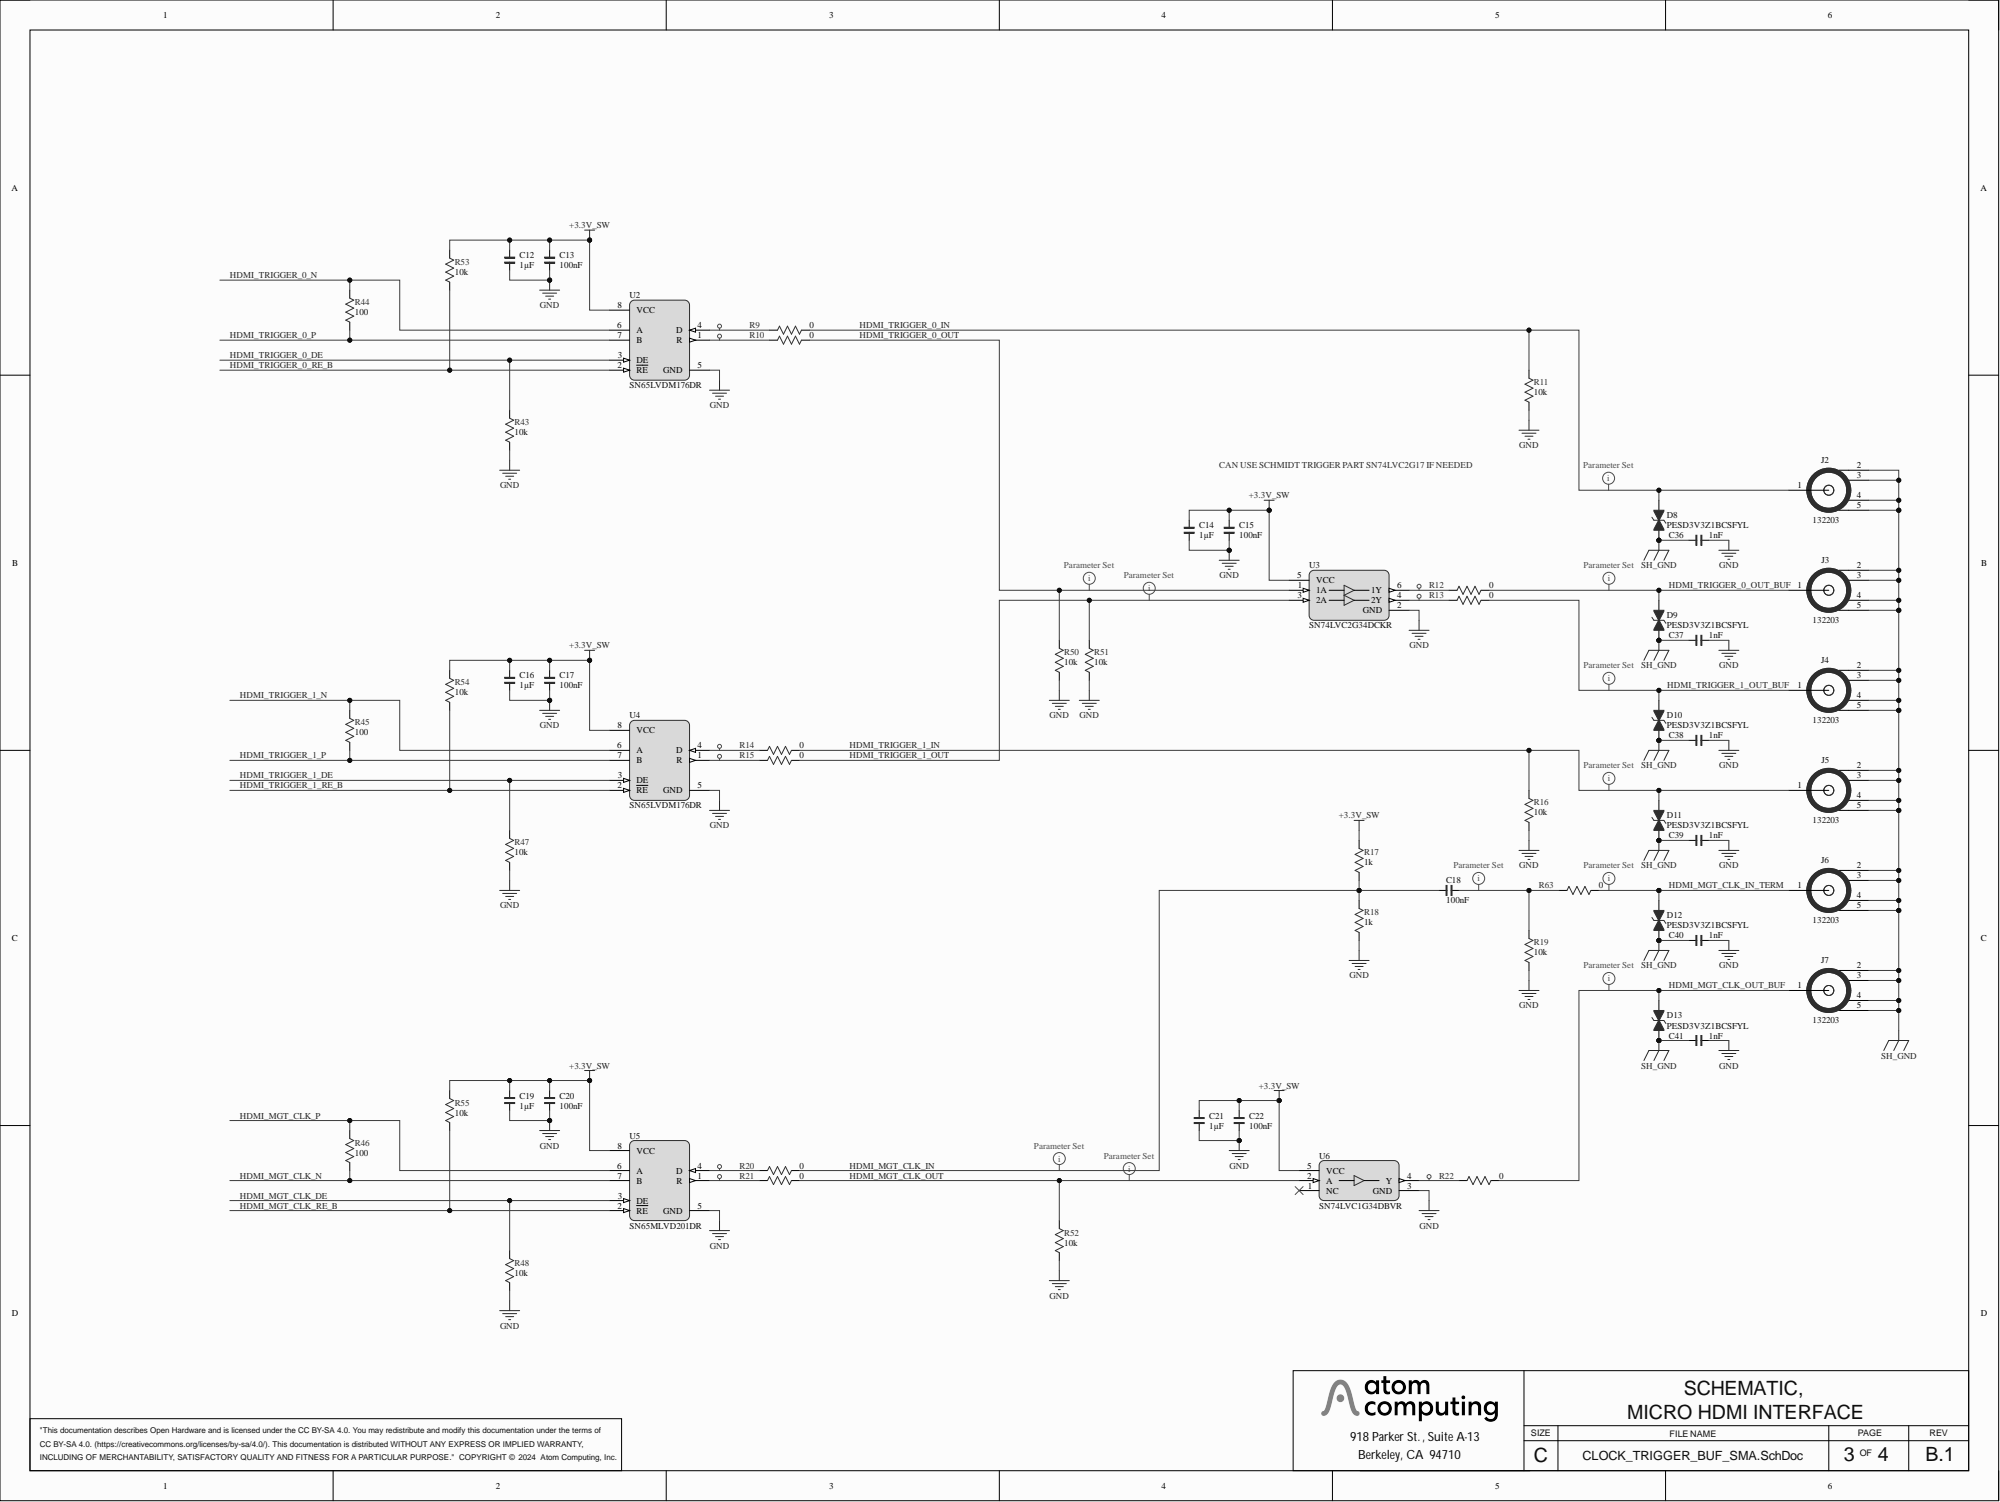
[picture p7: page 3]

SI Z | F ILE NAM E | PAGE OF | R E V
E C | CLO CK_TR I G GER_BUF_SMA.Sc h D o c

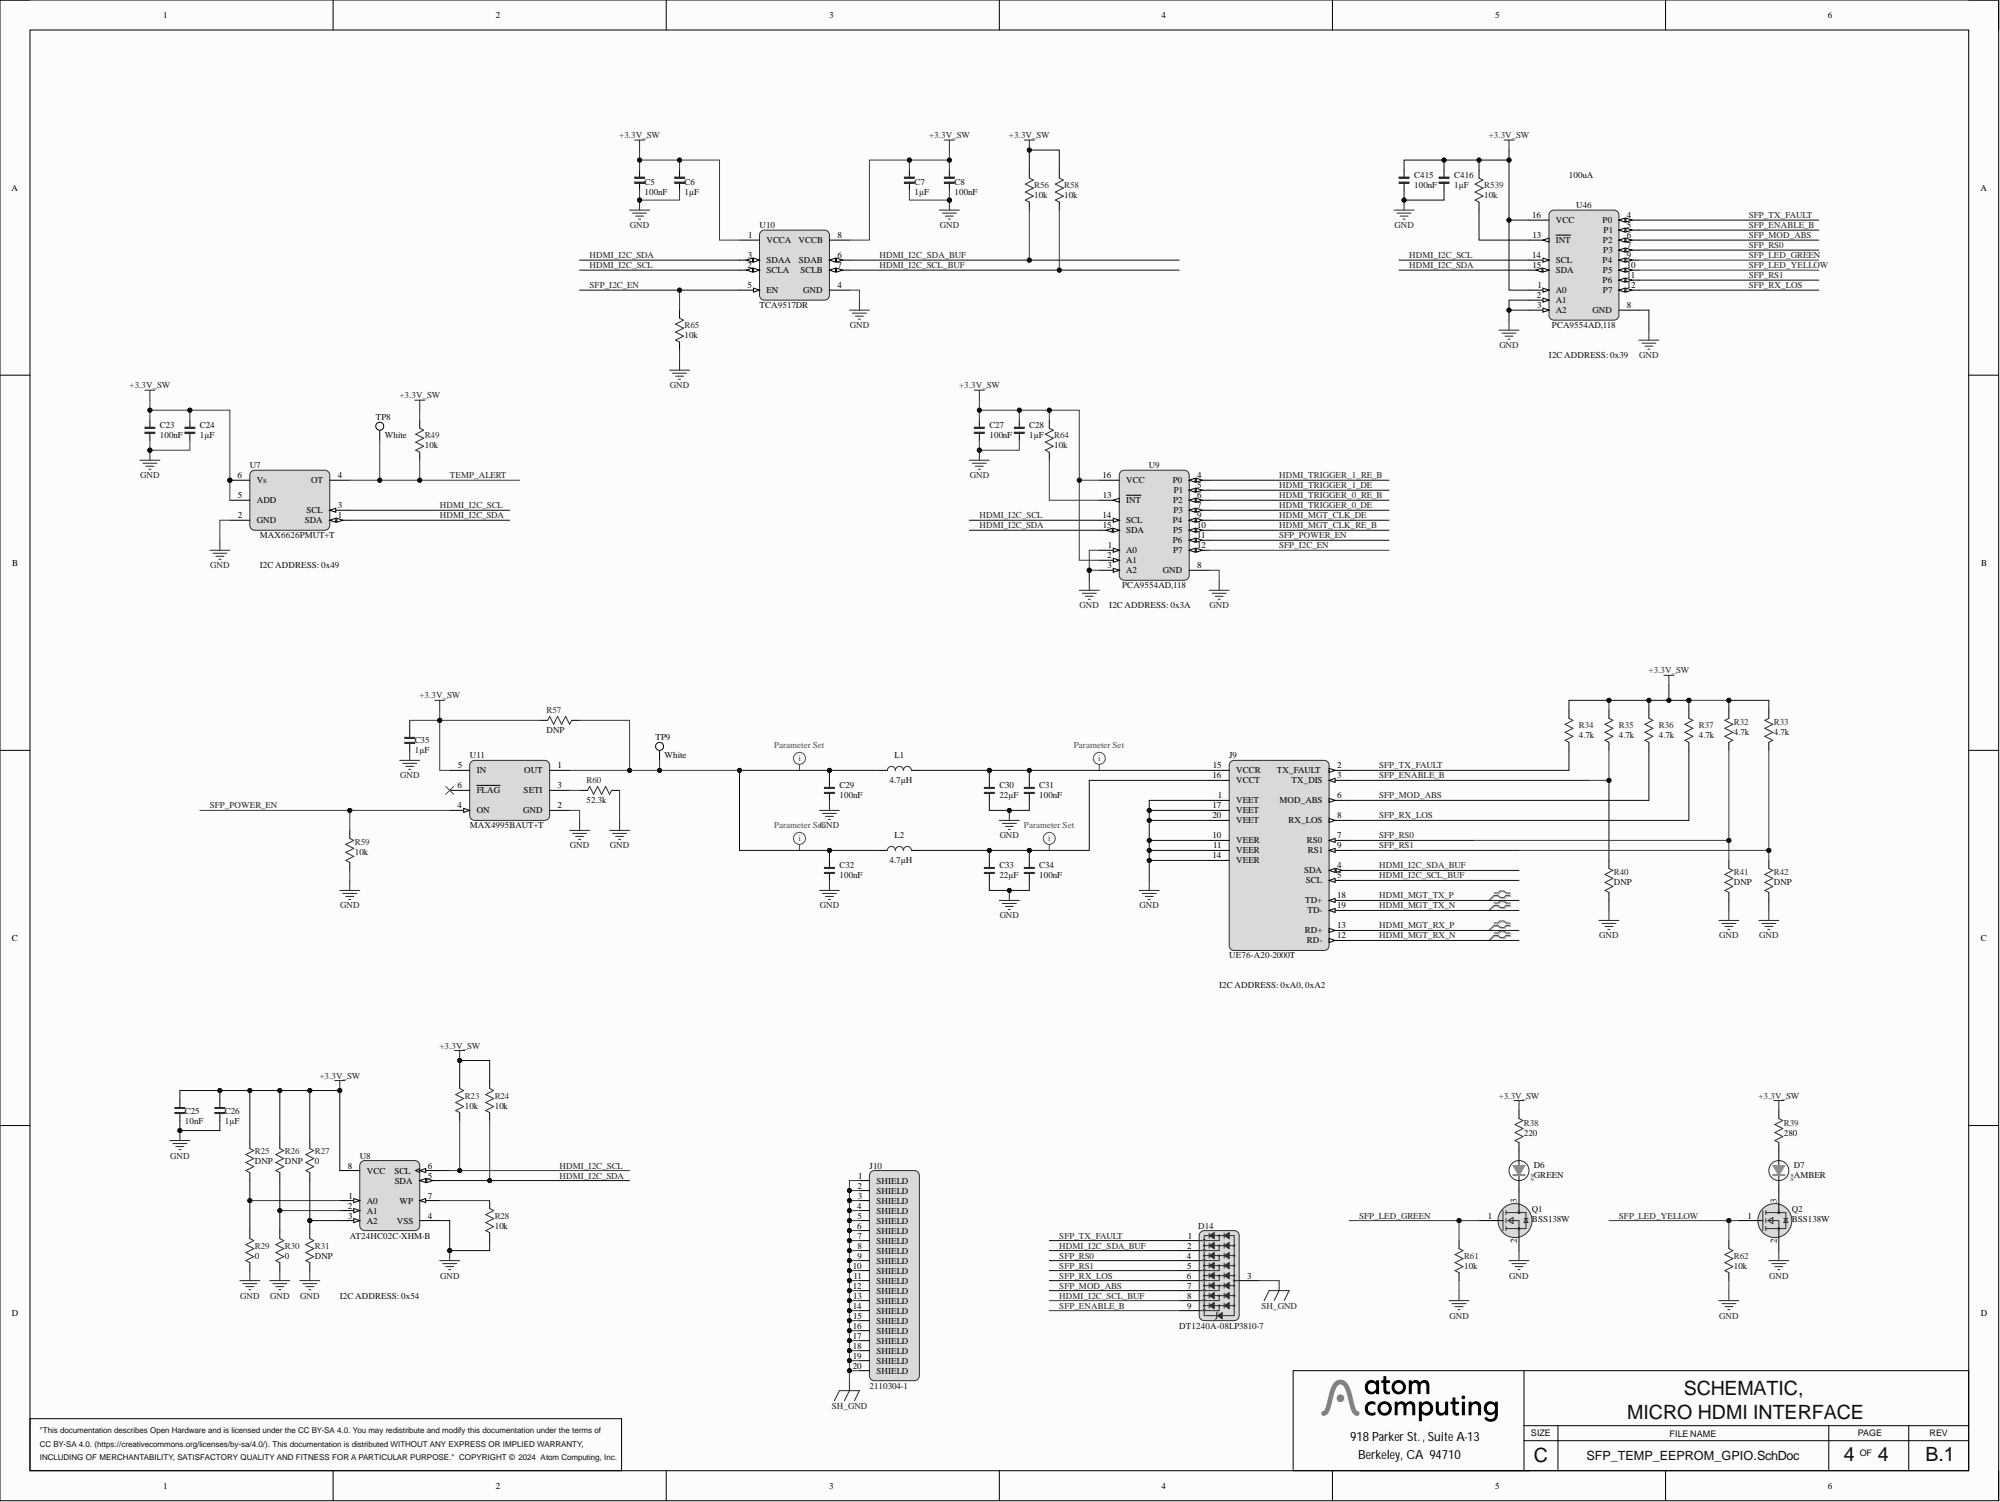
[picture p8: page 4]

SFP_MOD_ABS

SFP_RX_LOS

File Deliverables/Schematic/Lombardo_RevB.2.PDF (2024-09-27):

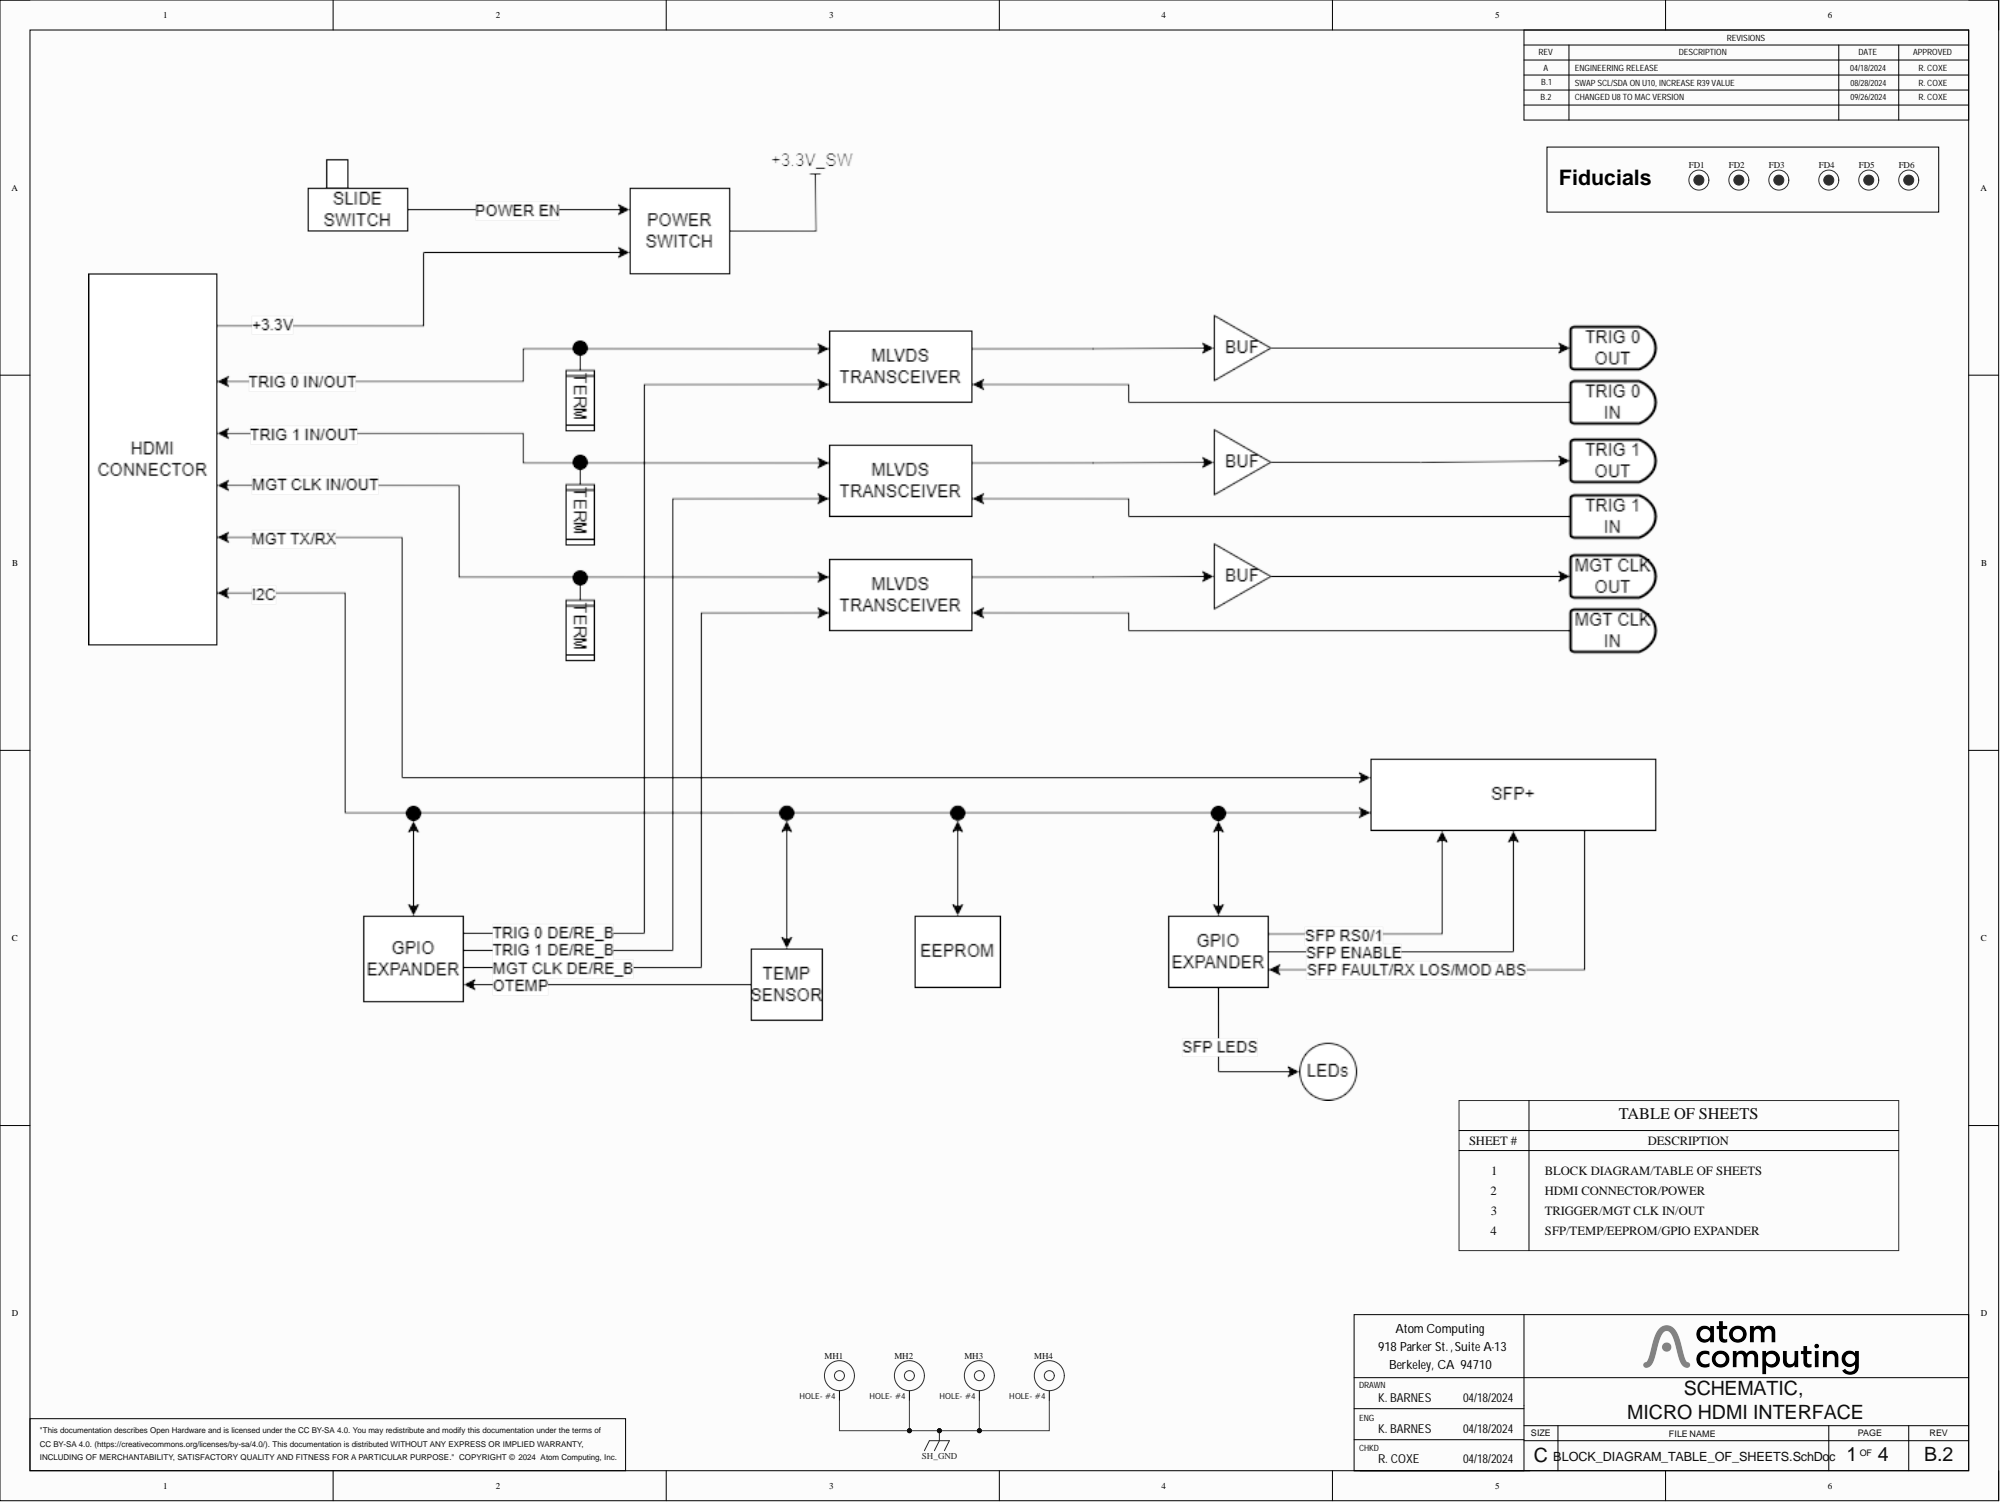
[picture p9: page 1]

REV | DESCRIPTION | DATE | APPROVED

A | ENGINEERING RELEASE | 04/18/2024 | R. COXE
B.1 | SWAP SCL/SDA ON U10, INCREASE R39 VALUE | 08/28/2024 | R. COXE
B.2 | CHANGED U8 TO MAC VERSION | 09/26/2024 | R. COXE

TABLE OF SHEETS

SHEET # | DESCRIPTION

1 2 3 4 | BLOCK DIAGRAM/TABLE OF SHEETS HDMI CONNECTOR/POWER TRIGGER/MGT CLK IN/OUT SFP/TEMP/EEPROM/GPIO EXPANDER

Atom Computing 918 Parker St. , Suite A-13 Berkeley, CA 94710

DRAWN K. BARNES 04/18/2024 | SCHEMATIC, MICRO HDMI INTERFACE

"This documentation describes Open Hardware and is licensed under the CC BY-SA 4.0. You may redistribute and modify this documentation under the terms of
CC BY-SA 4.0. (https://creativecommons.org/licenses/by-sa/4.0/). This documentation is distributed WITHOUT ANY EXPRESS OR IMPLIED WARRANTY,

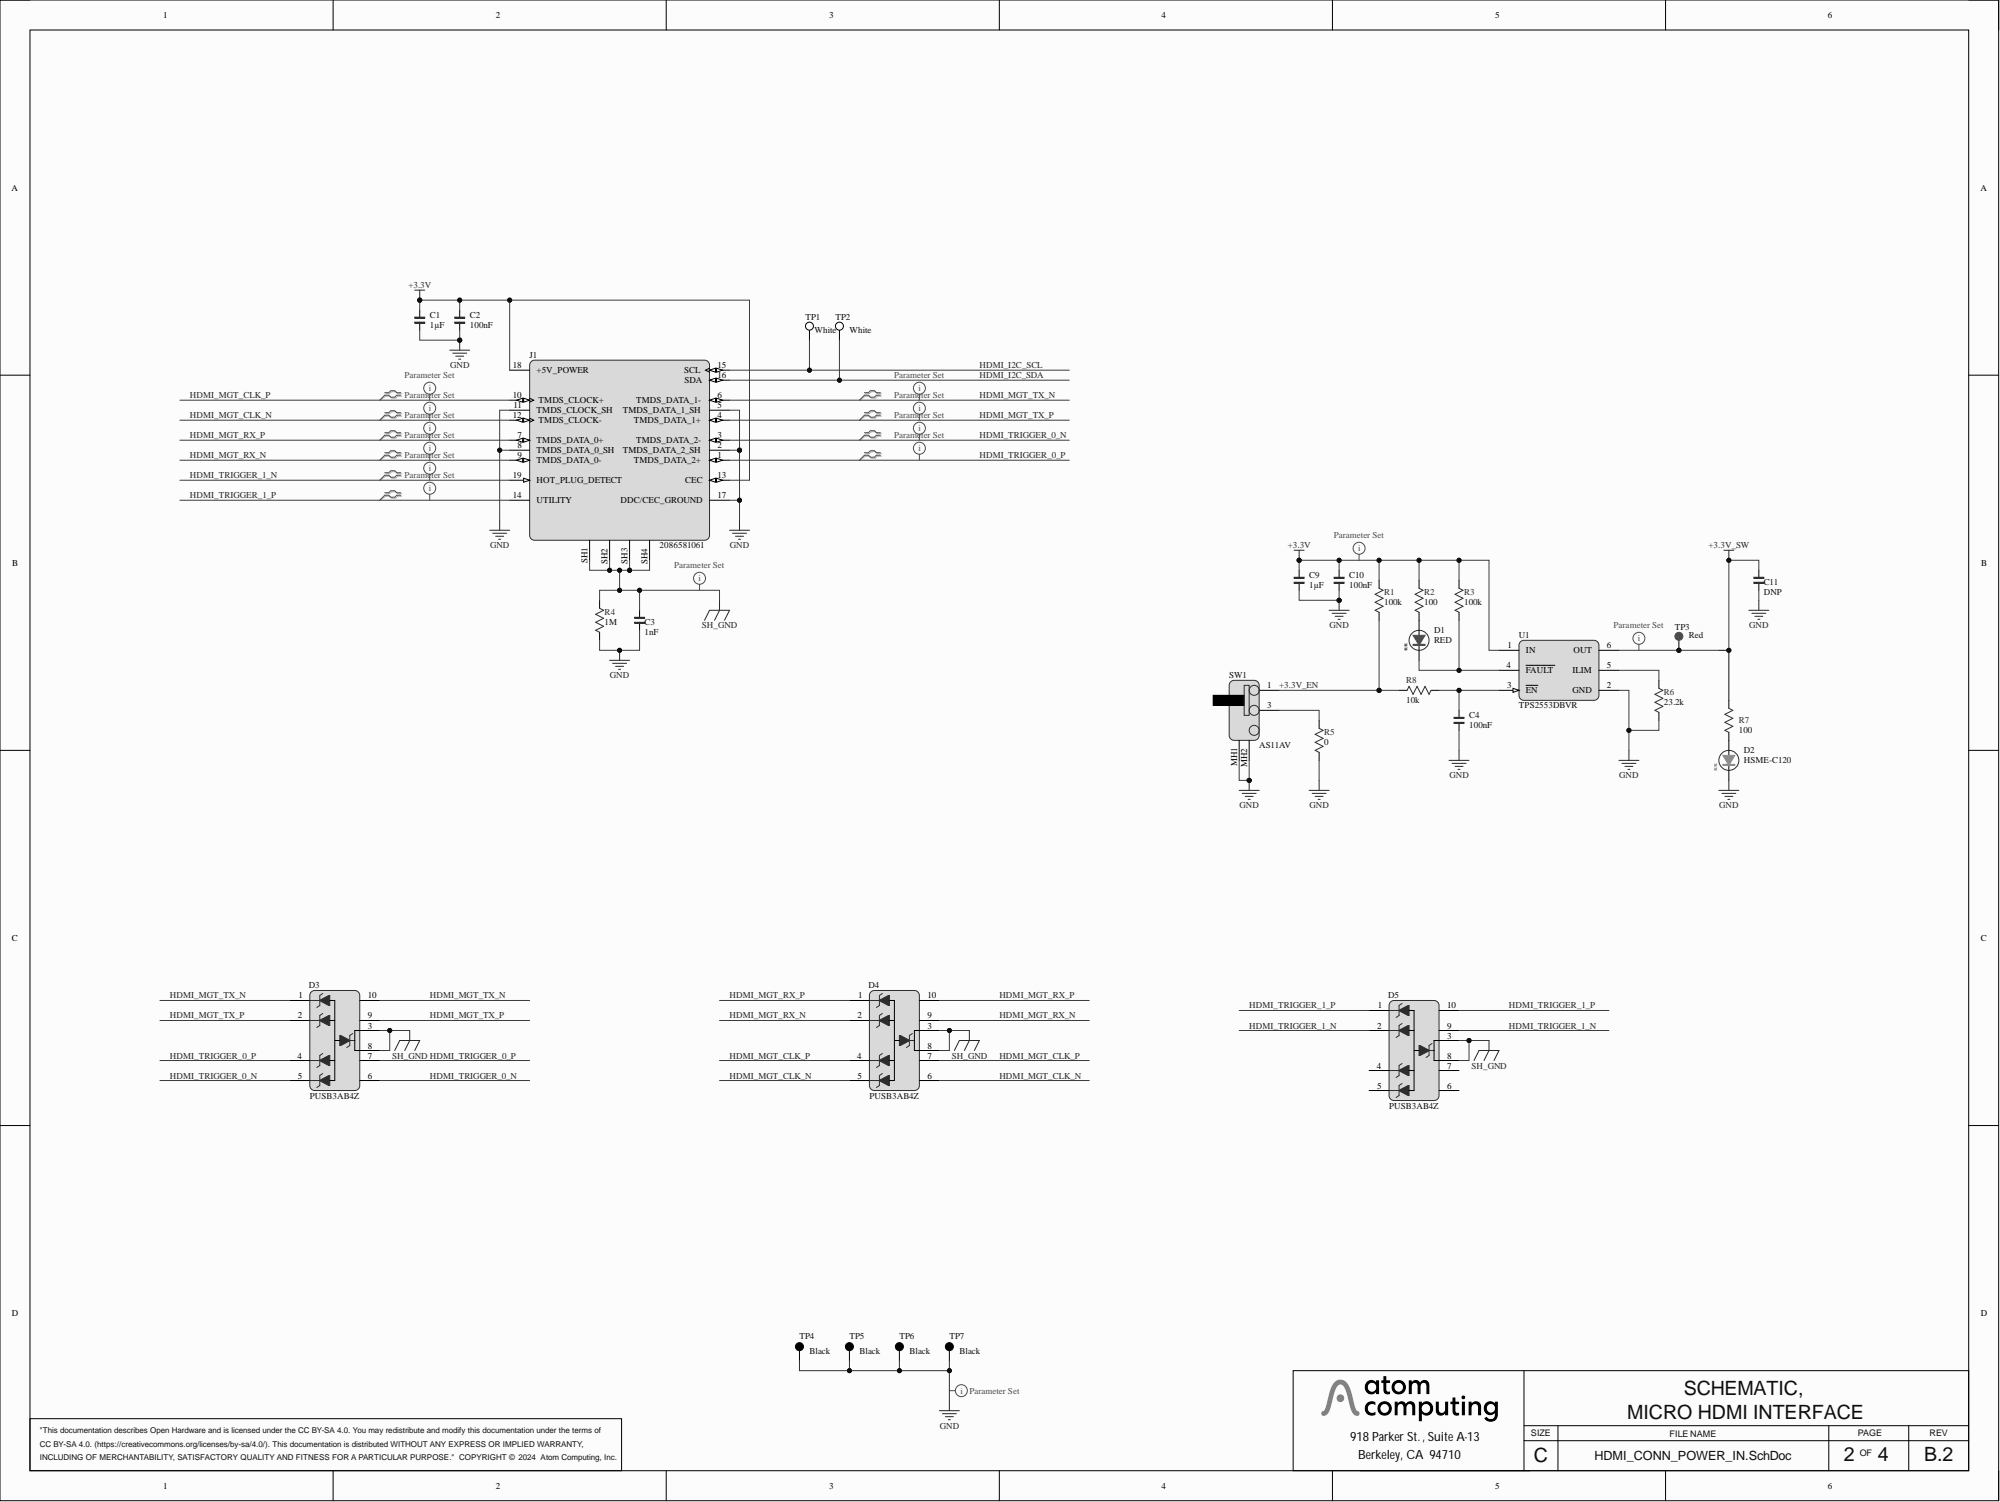
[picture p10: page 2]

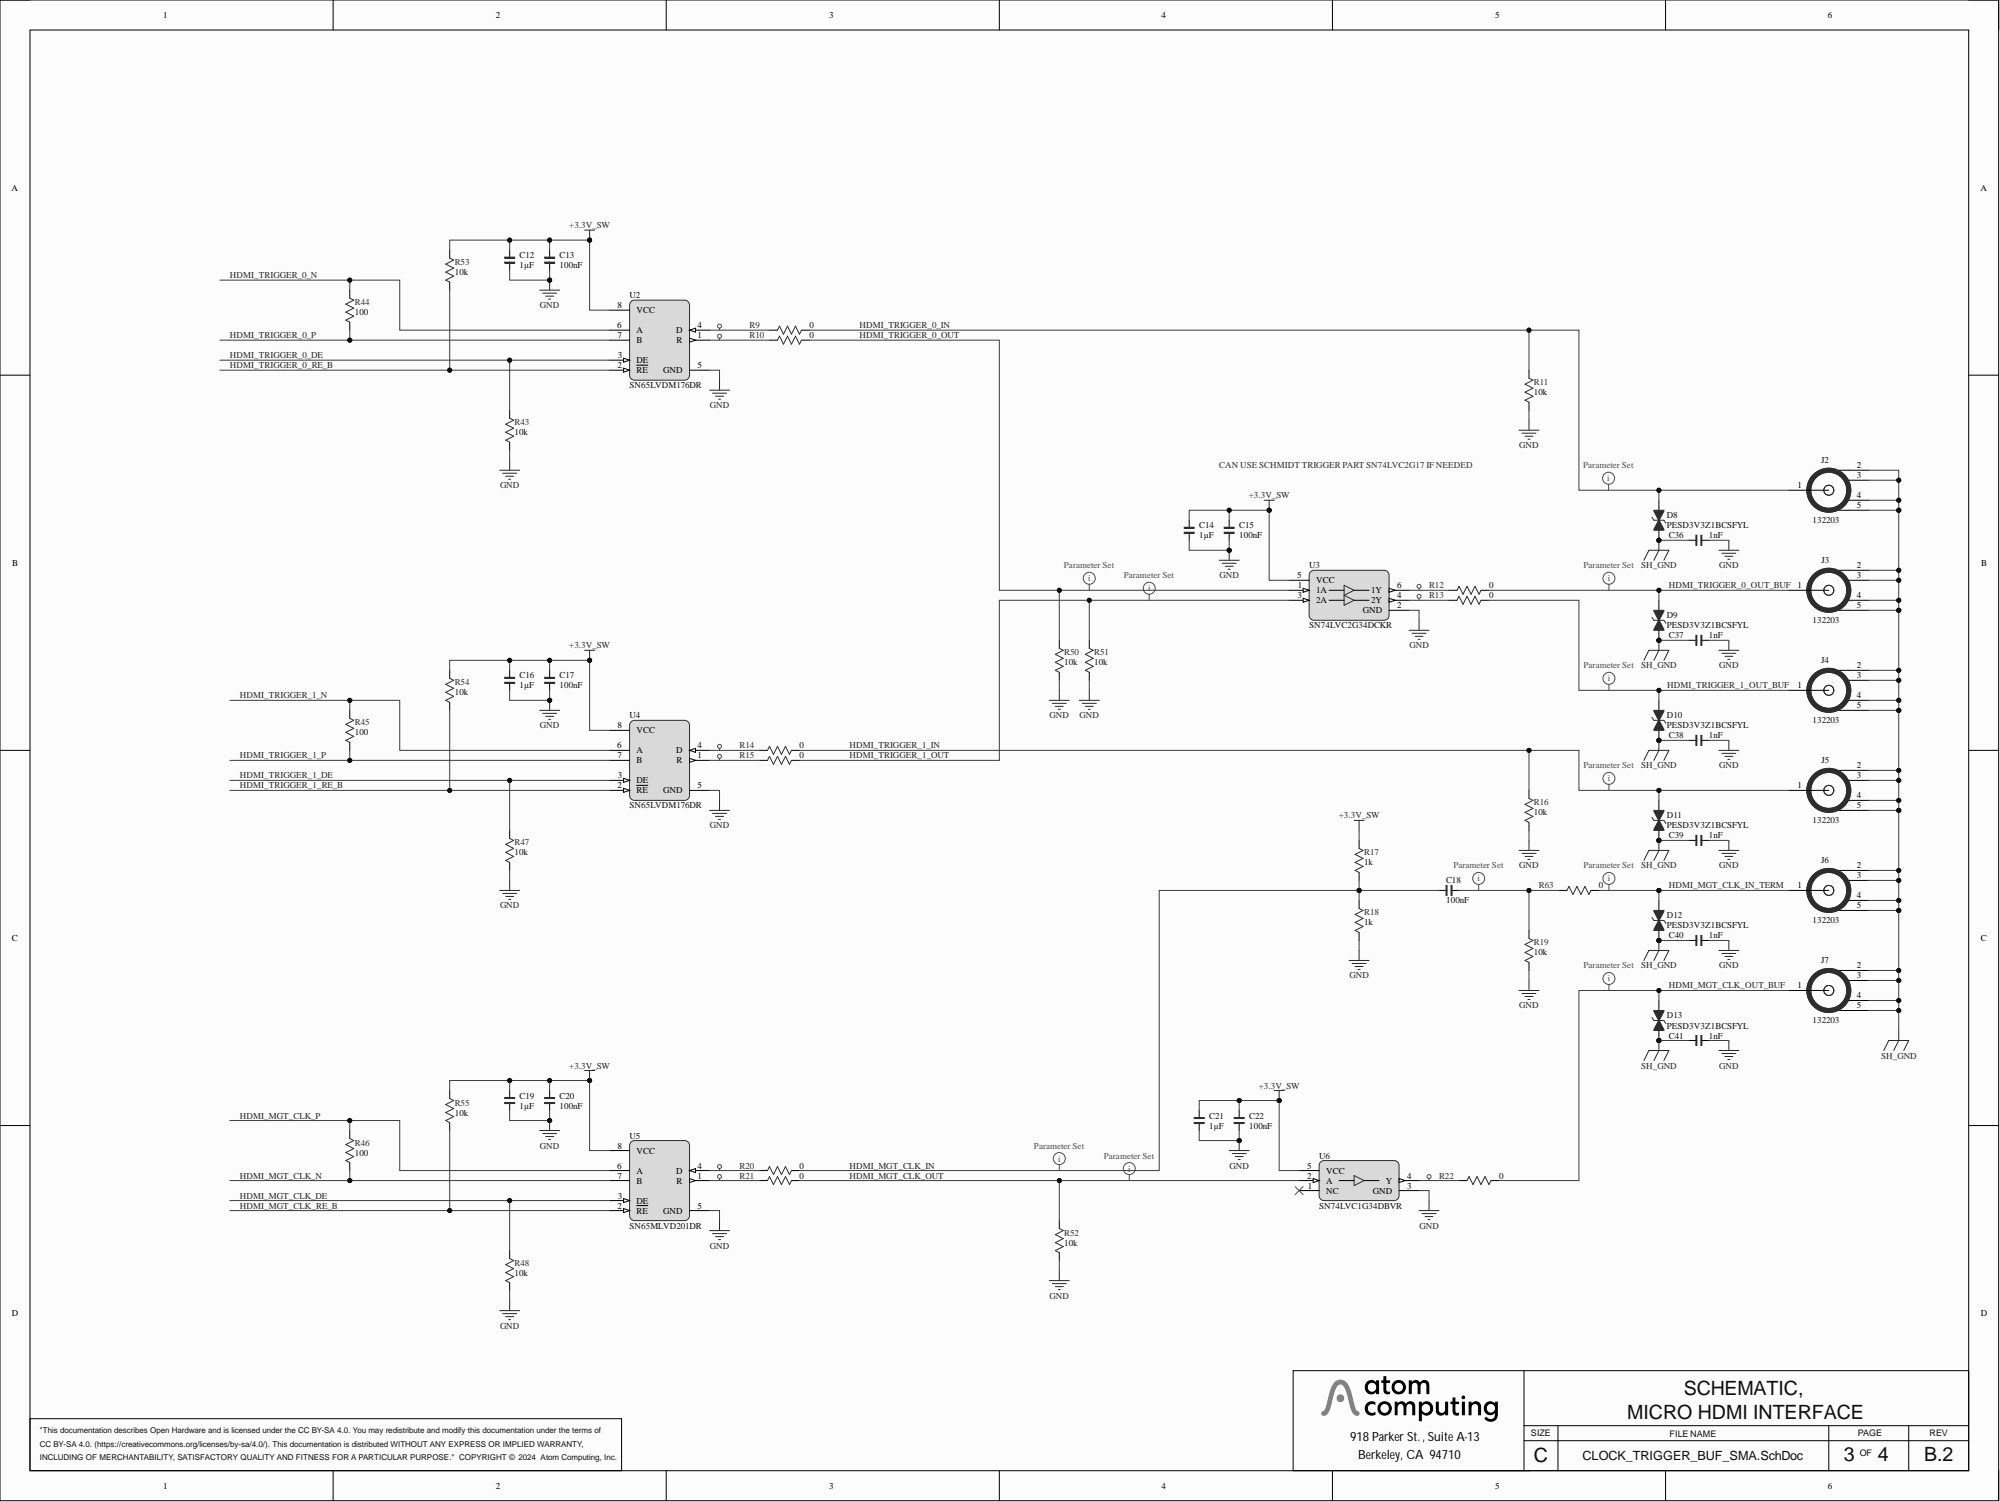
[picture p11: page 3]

SI Z | F ILE NAM E | PAGE OF | R E V
E C | CLO CK_TR I G GER_BUF_SMA.Sc h D o c

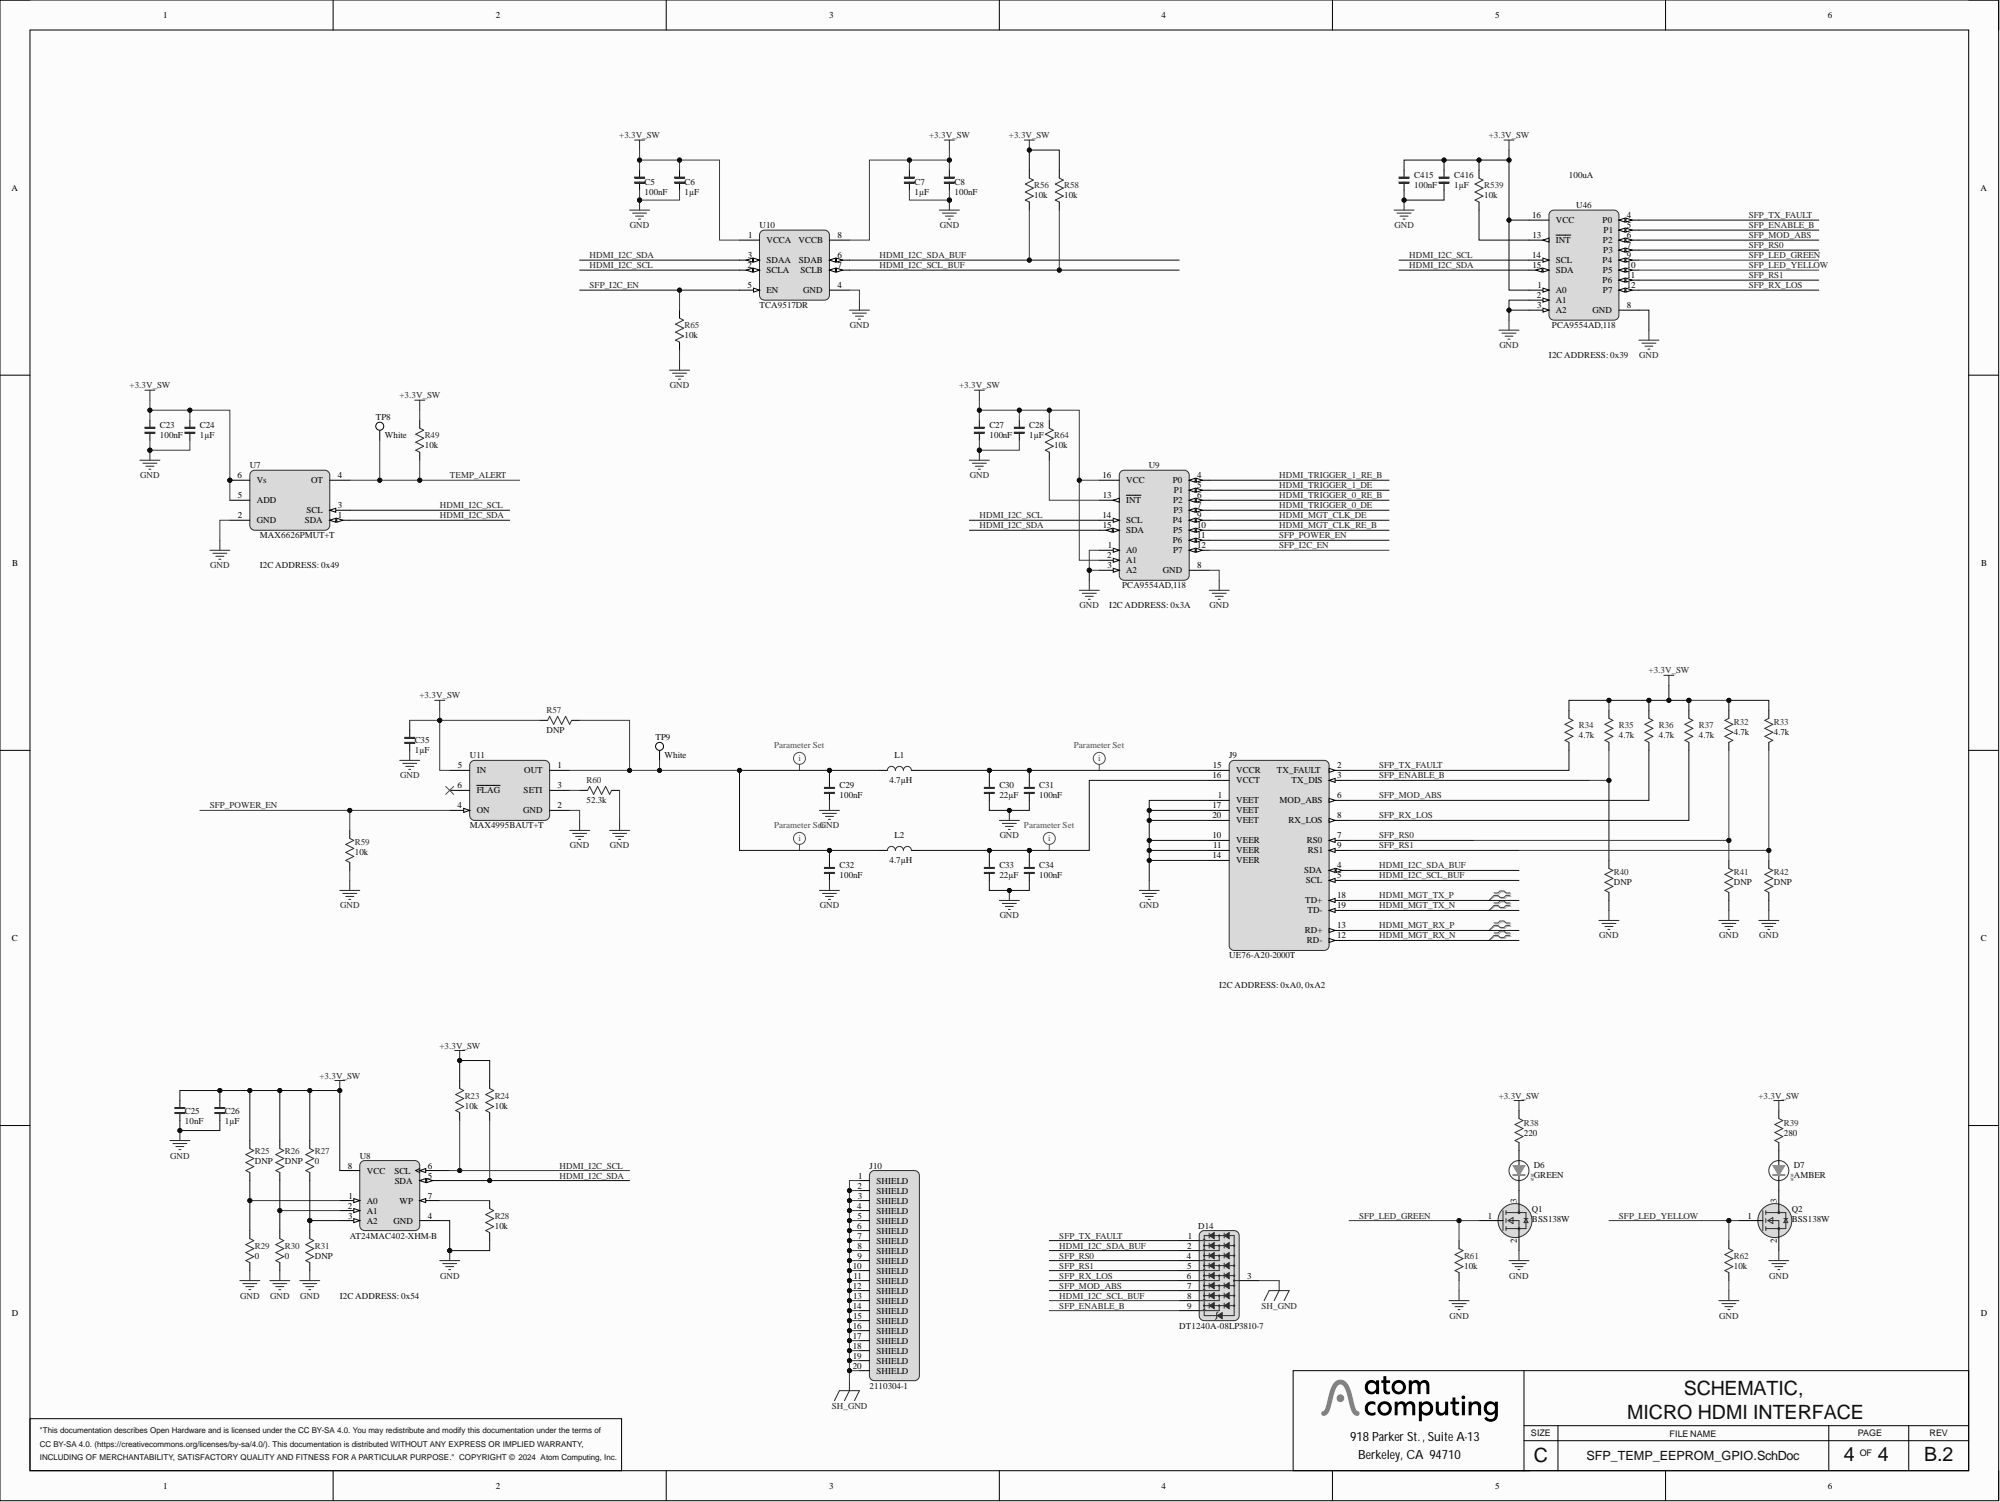
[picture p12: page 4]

SFP_MOD_ABS

SFP_RX_LOS

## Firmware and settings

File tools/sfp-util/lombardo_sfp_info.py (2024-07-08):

#! /usr/bin/env python3

# Copyright (c) 2024 Atom Computing, Inc.

import argparse
import ctypes
import logging

import smbus


class SfpEepromStruct(ctypes.BigEndianStructure):
    _pack_ = 1
    _fields_ = [
        ("identifier", ctypes.c_uint8),
        ("ext_identifier", ctypes.c_uint8),
        ("connector", ctypes.c_uint8),
        ("transceiver", ctypes.c_uint8 * 8),
        ("encoding", ctypes.c_uint8),
        ("br_nominal", ctypes.c_uint8),
        ("rate_identifier", ctypes.c_uint8),
        ("length_smf_km", ctypes.c_uint8),
        ("length_smf_100m", ctypes.c_uint8),
        ("length_om2_50um", ctypes.c_uint8),
        ("length_om1_62_5um", ctypes.c_uint8),
        ("length_om4_50um", ctypes.c_uint8),
        ("length_om3_50um", ctypes.c_uint8),
        ("vendor_name", ctypes.c_uint8 * 16),
        ("transceiver_code", ctypes.c_uint8),
        ("vendor_oui", ctypes.c_uint8 * 3),
        ("vendor_pn", ctypes.c_uint8 * 16),
        ("vendor_rev", ctypes.c_uint8 * 4),
        ("wavelength", ctypes.c_uint16),
        ("fibre_channel_speed", ctypes.c_uint8),
        ("cc_base", ctypes.c_uint8),
        ("options", ctypes.c_uint16),
        ("br_max", ctypes.c_uint8),
        ("br_min", ctypes.c_uint8),
        ("vendor_sn", ctypes.c_uint8 * 16),
        ("date_code", ctypes.c_uint8 * 8),
        ("diagnostics", ctypes.c_uint8),
        ("enhanced_options", ctypes.c_uint8 * 2),
        ("sff_8472_compliance", ctypes.c_uint8),
        ("cc_ext", ctypes.c_uint8),
        ("vendor_specific", ctypes.c_uint8 * 32),
    ]


class SfpEepromOptionstruct(ctypes.BigEndianStructure):
    _pack_ = 1
    _fields_ = [
        ("rsvd15", ctypes.c_uint8, 1),
        ("high_power2", ctypes.c_uint8, 1),
        ("high_power", ctypes.c_uint8, 1),
        ("paging", ctypes.c_uint8, 1),
        ("retimer", ctypes.c_uint8, 1),
        ("cooled_xcvr", ctypes.c_uint8, 1),
        ("pow_lvl_decl", ctypes.c_uint8, 1),
        ("lin_recv", ctypes.c_uint8, 1),
        ("rx_decision_thr", ctypes.c_uint8, 1),
        ("tunable_tx", ctypes.c_uint8, 1),
        ("rate_select", ctypes.c_uint8, 1),
        ("tx_disable", ctypes.c_uint8, 1),
        ("tx_fault", ctypes.c_uint8, 1),
        ("signal_detect", ctypes.c_uint8, 1),
        ("loss_of_signal", ctypes.c_uint8, 1),
        ("rsvd0", ctypes.c_uint8, 1),
    ]


class SfpEepromDiagTypeStruct(ctypes.BigEndianStructure):
    _pack_ = 1
    _fields_ = [
        ("rsvd7", ctypes.c_uint8, 1),
        ("ddm_implemented", ctypes.c_uint8, 1),
        ("internal_calib", ctypes.c_uint8, 1),
        ("external_calib", ctypes.c_uint8, 1),
        ("addr_change", ctypes.c_uint8, 1),
        ("rsvd1_0", ctypes.c_uint8, 2),
    ]


class SfpMonitorStruct(ctypes.BigEndianStructure):
    _pack_ = 1
    _fields_ = [
        ("temp_high_alarm", ctypes.c_int16),
        ("temp_low_alarm", ctypes.c_int16),
        ("temp_high_warning", ctypes.c_int16),
        ("temp_low_warning", ctypes.c_int16),
        ("vcc_high_alarm", ctypes.c_uint16),
        ("vcc_low_alarm", ctypes.c_uint16),
        ("vcc_high_warning", ctypes.c_uint16),
        ("vcc_low_warning", ctypes.c_uint16),
        ("tx_bias_high_alarm", ctypes.c_uint16),
        ("tx_bias_low_alarm", ctypes.c_uint16),
        ("tx_bias_high_warning", ctypes.c_uint16),
        ("tx_bias_low_warning", ctypes.c_uint16),
        ("tx_power_high_alarm", ctypes.c_uint16),
        ("tx_power_low_alarm", ctypes.c_uint16),
        ("tx_power_high_warning", ctypes.c_uint16),
        ("tx_power_low_warning", ctypes.c_uint16),
        ("rx_power_high_alarm", ctypes.c_uint16),
        ("rx_power_low_alarm", ctypes.c_uint16),
        ("rx_power_high_warning", ctypes.c_uint16),
        ("rx_power_low_warning", ctypes.c_uint16),
        ("rsvd40_55", ctypes.c_uint8 * 16),
        ("rx_power_4", ctypes.c_float),
        ("rx_power_3", ctypes.c_float),
        ("rx_power_2", ctypes.c_float),
        ("rx_power_1", ctypes.c_float),
        ("rx_power_0", ctypes.c_float),
        ("tx_curr_slope", ctypes.c_uint16),
        ("tx_curr_offset", ctypes.c_uint16),
        ("tx_pwr_slope", ctypes.c_uint16),
        ("tx_pwr_offset", ctypes.c_uint16),
        ("t_slope", ctypes.c_uint16),
        ("t_offset", ctypes.c_uint16),
        ("v_slope", ctypes.c_uint16),
        ("v_offset", ctypes.c_uint16),
        ("rsvd92_94", ctypes.c_uint8 * 3),
        ("checksum", ctypes.c_uint8),
        # "Table 9-16 A/D Values and Status Bits"
        ("temp", ctypes.c_int16),
        ("vcc", ctypes.c_uint16),
        ("tx_bias", ctypes.c_uint16),
        ("tx_power", ctypes.c_uint16),
        ("rx_power", ctypes.c_uint16),
        ("optional_laser_temp", ctypes.c_uint16),
        ("optional_tec_current", ctypes.c_uint16),
        ("status_control_bits", ctypes.c_uint8),
        ("rsvd111", ctypes.c_uint8),
        ("alarms", ctypes.c_uint16),
        ("tx_equalizer_ctrl", ctypes.c_uint8),
        ("rx_emphasis_ctrl", ctypes.c_uint8),
        ("warnings", ctypes.c_uint16),
        ("extended_status", ctypes.c_uint16),
    ]


class SfpMonitorStatusControlStruct(ctypes.BigEndianStructure):
    _pack_ = 1
    _fields_ = [
        ("tx_disable", ctypes.c_uint8, 1),
        ("soft_tx_disable", ctypes.c_uint8, 1),
        ("rs1_state", ctypes.c_uint8, 1),
        ("rs0_state", ctypes.c_uint8, 1),
        ("soft_rs0", ctypes.c_uint8, 1),
        ("tx_fault", ctypes.c_uint8, 1),
        ("rx_los", ctypes.c_uint8, 1),
        ("data_not_ready", ctypes.c_uint8, 1),
    ]


def hexdump(logging_func, bs):
    BYTES_PER_LINE = 16

    logging_func("    | ", end="")
    for i in range(BYTES_PER_LINE):
        logging_func(f"{i:02x} ", end="")
    logging_func("")

    logging_func("----+-", end="")
    for i in range(BYTES_PER_LINE):
        logging_func("---", end="")
    logging_func("")

    for i in range(0, len(bs), BYTES_PER_LINE):
        logging_func(f"{i:3x} | ", end="")
        for j in range(BYTES_PER_LINE):
            if i + j < len(bs):
                logging_func(f"{bs[i+j]:02x} ", end="")
            else:
                logging_func("   ", end="")
        logging_func("")


class SfpInfo:
    def __init__(self, bus_index: int):
        self.logger = logging.getLogger("SfpInfo")
        self.bus_index = bus_index

    def _get_eeprom_data(self) -> bytes:
        bus = smbus.SMBus(self.bus_index)

        eeprom_data = b""
        for i in range(0, 256, 16):
            eeprom_data += bytes(bus.read_i2c_block_data(0x50, i, 16))

        self.logger.debug("EEPROM data:")
        if self.logger.isEnabledFor(logging.DEBUG):
            hexdump(print, eeprom_data)

        return eeprom_data

    def _get_monitor_data(self) -> bytes:
        bus = smbus.SMBus(self.bus_index)

        monitor_data = b""
        for i in range(0, 256, 16):
            monitor_data += bytes(bus.read_i2c_block_data(0x51, i, 16))

        self.logger.debug("Monitor data:")
        if self.logger.isEnabledFor(logging.DEBUG):
            hexdump(print, monitor_data)

        return monitor_data

    def _print_eeprom(self, eeprom: bytes):
        print("  Info:")
        sfp_eeprom_struct = SfpEepromStruct.from_buffer_copy(eeprom)
        print(f"    Vendor name      : {str(sfp_eeprom_struct.vendor_name, 'ascii')}")
        print(f"    Vendor PN        : {str(sfp_eeprom_struct.vendor_pn, 'ascii')}")
        print(f"    Vendor rev       : {str(sfp_eeprom_struct.vendor_rev, 'ascii')}")
        print(f"    Vendor SN        : {str(sfp_eeprom_struct.vendor_sn, 'ascii')}")
        print(f"    Vendor OUI       : {':'.join([f'{x:02x}' for x in sfp_eeprom_struct.vendor_oui])}")
        date_code_str = str(sfp_eeprom_struct.date_code, "ascii")
        print(f"    Date code        : 20{date_code_str[0:2]}-{date_code_str[2:4]}-{date_code_str[4:6]}")
        print(f"    Wavelength       : {sfp_eeprom_struct.wavelength} nm")
        print(f"    Length (OM2/50um): {sfp_eeprom_struct.length_om2_50um * 10} m")
        print(f"    Length (OM4/50um): {sfp_eeprom_struct.length_om4_50um * 10} m")
        print(f"    Encoding         : 0x{sfp_eeprom_struct.encoding:02x} (", end="")
        if sfp_eeprom_struct.encoding == 0x01:
            print("8B/10B", end="")
        elif sfp_eeprom_struct.encoding == 0x02:
            print("4B/5B", end="")
        elif sfp_eeprom_struct.encoding == 0x03:
            print("NRZ", end="")
        elif sfp_eeprom_struct.encoding == 0x04:
            print("Manchester", end="")
        elif sfp_eeprom_struct.encoding == 0x05:
            print("SONET Scrambled", end="")
        elif sfp_eeprom_struct.encoding == 0x06:
            print("64B/66B", end="")
        print(")")

        print(f"    Baud rate        : {sfp_eeprom_struct.br_nominal * 100} Mbit/s")
        print(f"    Options:         : 0x{sfp_eeprom_struct.options:04x}")
        option = SfpEepromOptionstruct.from_buffer_copy(sfp_eeprom_struct.options.to_bytes(2, byteorder="big"))
        print(f"      Retimer/CDR      : {option.retimer}")
        print(f"      Rate Select      : {option.rate_select}")
        print(f"      Tx Disable       : {option.tx_disable}")
        print(f"      Tx Fault         : {option.tx_fault}")
        print(f"      Loss of Signal   : {option.loss_of_signal}")

        print(f"    Diagnostic       : 0x{sfp_eeprom_struct.diagnostics:02x}")
        diag_type = SfpEepromDiagTypeStruct.from_buffer_copy(sfp_eeprom_struct.diagnostics.to_bytes(1, "little"))
        print(f"      Addr change      : {diag_type.addr_change}")
        print(f"      External calib   : {diag_type.external_calib}")
        print(f"      Internal calib   : {diag_type.internal_calib}")
        print(f"      DDM implemented  : {diag_type.ddm_implemented}")

        return diag_type.ddm_implemented

    def _print_monitor(self, monitor_data: bytes):
        mon = SfpMonitorStruct.from_buffer_copy(monitor_data)

        # check if the coefficients are the ones for internal calibration
        # external calibration is not implemented yet
        assert mon.rx_power_4 == 0.0, f"coef rx_power_4 is {mon.rx_power_4}, should be 0.0"
        assert mon.rx_power_3 == 0.0, f"coef rx_power_3 is {mon.rx_power_3}, should be 0.0"
        assert mon.rx_power_2 == 0.0, f"coef rx_power_2 is {mon.rx_power_2}, should be 0.0"
        assert mon.rx_power_1 == 1.0, f"coef rx_power_1 is {mon.rx_power_1}, should be 1.0"
        assert mon.rx_power_0 == 0.0, f"coef rx_power_0 is {mon.rx_power_0}, should be 0.0"
        assert mon.tx_curr_slope == 256, f"coef tx_curr_slope is {mon.tx_curr_slope}, should be 256"
        assert mon.tx_curr_offset == 0, f"coef tx_curr_offset is {mon.tx_curr_offset}, should be 0"
        assert mon.tx_pwr_slope == 256, f"coef tx_pwr_slope is {mon.tx_pwr_slope}, should be 256"
        assert mon.tx_pwr_offset == 0, f"coef tx_pwr_offset is {mon.tx_pwr_offset}, should be 0"
        assert mon.t_slope == 256, f"coef t_slope is {mon.t_slope}, should be 256"
        assert mon.t_offset == 0, f"coef t_offset is {mon.t_offset}, should be 0"
        assert mon.v_slope == 256, f"coef v_slope is {mon.v_slope}, should be 256"
        assert mon.v_offset == 0, f"coef v_offset is {mon.v_offset}, should be 0"

        print("  Monitor:")
        print(f"    Temp     : {mon.temp / 256:.02f} degC")
        print(f"    Vcc      : {mon.vcc / 10000:.03f} V")
        print(f"    Tx Bias  : {mon.tx_bias / 500:.02f} mA")
        print(f"    Tx Power : {mon.tx_power / 10000:.03f} mW")
        print(f"    Rx Power : {mon.rx_power / 10000:.03f} mW")
        print(f"    Status/Control: 0x{mon.status_control_bits:02x}")

        status_control = SfpMonitorStatusControlStruct.from_buffer_copy(
            mon.status_control_bits.to_bytes(1, byteorder="big")
        )
        print(f"      Tx Disable: {status_control.tx_disable}")
        print(f"      RS1 State : {status_control.rs1_state}")
        print(f"      RS0 State : {status_control.rs0_state}")
        print(f"      Tx Fault  : {status_control.tx_fault}")
        print(f"      Rx LOS    : {status_control.rx_los}")

    def print_sfp_info(self):
        eeprom = self._get_eeprom_data()
        ddm_implemented = self._print_eeprom(eeprom)

        if ddm_implemented:
            monitor_data = self._get_monitor_data()
            self._print_monitor(monitor_data)


if __name__ == "__main__":
    parser = argparse.ArgumentParser(description="Read SFP EEPROM and monitor data")
    parser.add_argument("bus_index", type=int, help="I2C bus index")
    parser.add_argument("--debug", action="store_true", help="Enable debug output")
    args = parser.parse_args()

    if args.debug:
        logging.basicConfig(level=logging.DEBUG)

    sfp = SfpInfo(args.bus_index)
    sfp.print_sfp_info()

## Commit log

2024-07-08 dtbo: add I2C GPIO expanders
2024-07-08 dtbo: add temp sensor
2024-08-29 Add source files and deliverables for RevB
    [BLOCK_DIAGRAM_TABLE_OF_SHEETS.SchDoc, CLOCK_TRIGGER_BUF_SMA.SchDoc, HDMI_CONN_POWER_IN.SchDoc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]
2024-09-27 Add source files and deliverables for RevB.2
    [BLOCK_DIAGRAM_TABLE_OF_SHEETS.SchDoc, CLOCK_TRIGGER_BUF_SMA.SchDoc, HDMI_CONN_POWER_IN.SchDoc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]
2024-09-27 tools: dtbo: add a device with a MAC address
